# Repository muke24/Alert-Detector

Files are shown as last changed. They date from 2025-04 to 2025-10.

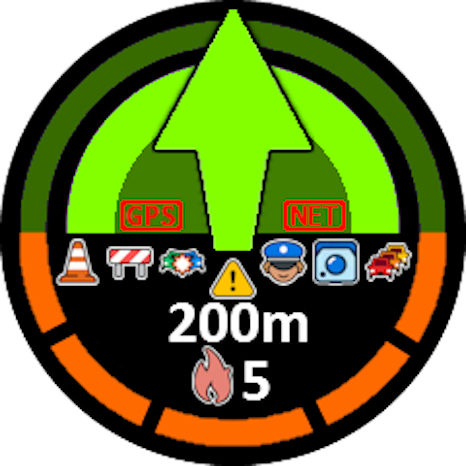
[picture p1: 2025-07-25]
Source/Images/Design/Design466.png

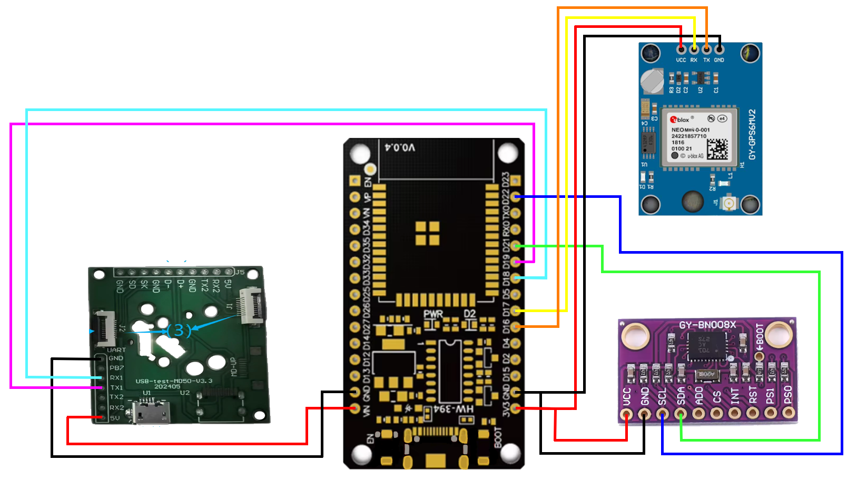
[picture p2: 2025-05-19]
Project Documents/Wiring Diagrams/V1/WiringDiagramV1.png

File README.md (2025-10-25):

Made for fun. I'd love for likeminded individuals to help with this project. I've been working on this idea for 3 years on and off, so make good use of it.

----------------------------------------
Description:

This project was inspired by the original Need for Speed Most Wanted (2005) which includes a device that uses Waze alert data which currently only points towards the closest police car. A really cool project which scrapes Waze API alert data (currently only POLICE alerts) and displays an arrow pointing towards the closest alert. It also shows the heat level, determined by how many police alerts are in the area. Along with that, the icon for the alert which was detected is also displayed, so if there are 3 police cars in the vicinity then 3 police icons will be shown.
The distance of the closest alert is also shown. Alert submission back to Waze does not exist, but if someone figured out how to, that would be cool.

This used to work perfectly, and if you use the Waze URL found within the code and paste it in to your search bar, you'll still see the JSON containing all of the alerts.
I think Waze may have patched this for devices which doesn't send cookie data, like this ESP32, but with some hacking around I think someone could get past this.
This code can be found in "Code/1_75 Inch/AlertFinder/AlertRetriever.cpp". Keep in mind this is a Waze backdoor API URL, use at your own risk. This could be changed at any time which it seems that some sort of security with it has changed and has not been working recently with the ESP32's I have tested recently. It still works within a Unity application as of currently - https://github.com/muke24/Civic_03

Uses DIY knob as inspiration found at https://github.com/scottbez1/smartknob. The youtube video I followed was: https://www.youtube.com/watch?v=ip641WmY4pA.
I used this as I did not want a cheap feel to the device, and makes it more premium and is stronger than a regular rotary encoder like an EC35 rotary encoder.
I also did not want to explicitly use touch, as touch screens and cars don't work well together in my humble opinion, so I wanted to use the touch screen as a sensor to know when the knob is pushed down, which would in theory make a haptic like vibration to replicate a button press. This has not been completed, but that was the idea.

I'd love to add a dashcam functionality and even AI detection of alerts, however the current device runs at about 15 frames per second, so this is not viable with this setup.
A Jetson Nano should do that job well, but that would get expensive. Definitely something I want to make though.

----------------------------------------

Data Source Warning: 
The device currently uses a reverse-engineered, non-public Waze URL. 
This method is fragile and likely violates Waze's Terms of Service. The URL is currently broken for the device (unsure of why, it works perfectly within Unity and it DID used to work on this ESP32, one day it just stopped working, not sure exactly what it is related to but AI told me its something to do with cookies, so there is a head start, maybe I just missed something, and if not I can already think of a few dodgy work arounds eg. get a server to pull the data instead and then get this device to pull from the server), 
so the first challenge for the community is to fix the access method. All code is provided under the MIT license."

----------------------------------------

PCB Warning:
PCB is untested. It is used to connect the ESP32 to the modules and power management. The ESP32 connects to this PCB by feeding 28AUG enameled copper wires through the hollow shaft motor. Do not hot glue the enamelled wires directly to the ESP32, but solder them onto the end of a 8 pin male header and push that into the device, seems to work pretty well.

----------------------------------------

Files for Creation

- Code: "Code/1_75 Inch/AlertFinder.ino"
- Models: "Models/13" (Read the README file in Models folder)
- PCB Files: PCB/1_75/kiCadWiringDiagram2025aug29/kiCadWiringDiagram

Parts: 
- ESP32: Waveshare 1.75Inch AMOLED ESP32-S3 (with GPS and Speaker) - https://www.waveshare.com/esp32-s3-touch-amoled-1.75.htm
- LED: (48leds used) 160 LEDs/m WS2812B 2.7mm width - https://www.aliexpress.com/item/1005006697141669.html?spm=a2g0o.order_list.order_list_main.172.643b18023ERucf
- Motor: 2804 iFlight Ipower - https://www.aliexpress.com/item/1005008389835260.html?spm=a2g0o.order_list.order_list_main.67.7c741802dJIMvc
(will test cheaper model eventually, I received 3 different types, there was a cheaper one that would have worked with some modeling work to add an encoder {https://www.aliexpress.com/item/4001123251754.html?spm=a2g0o.order_list.order_list_main.77.7c741802dJIMvc} but I received the iFlight first)
- PCB (To be sent to manufacturer JLCPCB)
- 28AUG Enamelled Wire
- 8 pin 2.54mm male header
- 10 Pin JST XH male header

On PCB:
- Magnetometer: MMC5883 (on PCB)
- Motor controller: TMC6300-LA (Might be changed on PCB if no stock is available)

M2 screws used.

----------------------------------------

TODO:

- Remove wire tray from "15" model and rename that to "16". (It was added to test things before I got a PCB manufactured, but even the tray was never used, so will need to fix that up)
- Code haptics and knob control for the motor
- Code LED's
- Code the magnetometer (merge the MMC5883 with the built-in 6 axis IMU on the Waveshare device to create a 9-axis IMU so that compass will work accurately)
- Code other Waze alerts and subtypes
- Code user settings so that brightness / selected alerts / ect can be modified
- Model universal mirror mounts so that the device can be held in place

Untested:
I have not yet manufactured a PCB.
I have not tested or coded the motor functionality. The motor will be used for haptics, and knob rotation feedback and selecting options such as changing alerts, brightness ect (not coded yet but you get the idea).
LED's have not yet been tested.
Pretty much anything connecting to the PCB hasn't been tested yet. I do however have coded all of these functions (except motor function) on the old version of this device (in the "Old" folder).

I do not want precise touch functionality, touch only exists to detect button presses. A mini touch screen makes no sense on a device made for use in a car to specifically reduce the need to even look at the Waze app for alert info.

I did make a different version with different parts. It was ugly and no model was made for it, but functionally it worked entirely (encoder worked, LED's worked and would flash at a speed dependant on how far the closest alert was, GUI was functional but showed no colour and was ugly, the arrow pointed at the closest police alert, speaker made OG NFSMW radar sounds which also played repeatedly dependant on how far the closest alert was). This can be found somewhere in the "Old" folder. I've provided Google Drive links with videos of the old version working with real alerts.

----------------------------------------

Additional Remarks:

If I were to pick and choose any future ideas, I would do this -

Models
Multiple models with differing price ranges:
- Cheapest: 1.46i Waveshare AMOLED with regular rotary encoder. Similar design to how it is now but cheaper and simpler. (Around $120 AUD)
- Mid Range: 1.75i Waveshare AMOLED (this design) but with added dashcam functionality. (Around $275 AUD)
- Flagship: 1.75i AMOLED using Nvidia Jetson Nano with dashcam and AI alert auto detection (Around a steap $850 AUD). (I know this is pretty ambitious, wanna team up Waze?)

Software
- A phone app to change settings and view dashcam videos if it were to be added. 
- AI Auto detection of alerts via camera.
- Alert Reporting

Hardware
- (Flagship) Dual PTZ Camera's for better long distance accuracy. LIDAR won't work through glass.
- (Flagship) Custom PCB built within the enclosure instead of the knob.

----------------------------------------

Pictures taken throughout development:

https://github.com/user-attachments/assets/8ef88b90-4c08-46e0-89e6-efae050536bf









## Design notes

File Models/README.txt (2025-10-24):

The "13" model is the one seen in the pictures on the GitHub.

The bottom tray was added in 14 & 15 as I was assuming I was going to wire everything together and put the wires inside the bottom tray, but it's cheaper and easier if a PCB is made, so I hired a freelancer to do it. They weren't able to complete within budget as there were some issues that were needed to be fixed.

Also, "14" and "15" have the GPS holder, which will need to be added to "13". Either modify "13" to have the GPS holder, or remove the tray on "15".

Specifically,
JLCPCB didn't have stock of the motor controller, and PCBWay replied saying there was an issue:

"In your gerber files, some pads clearance in copper layer is smaller than 0.22mm,
therefore, solder mask bridge is not available. If you need black solder mask in these areas
as the attached pic1 showed, pls enlarge space to 0.22mm or there will be no solder mask
between those pads, which may cause short circuit. Pls check and advise".

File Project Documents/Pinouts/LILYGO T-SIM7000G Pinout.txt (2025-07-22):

LILYGO T-SIM7000G V1.1 Pinout

Left side:
       |        |       | 3V3
       |        |       | GND
Pin 32 | GPIO32 | ADC04 | TOUCH9
Pin 33 | GPIO33 | ADC05 | TOUCH8
Pin 34 | GPIO34 | ADC06 | TOUCH7
Pin 35 | GPIO35 | ADC07 | TOUCH6
Pin 25 | GPIO25 | DAC1  | 
Pin 26 | GPIO26 | DAC2  | 
Pin 27 | GPIO27 | ADC17 | TOUCH0
Pin 14 | GPIO14 | ADC12 | TOUCH2
Pin 13 | GPIO13 | ADC14 | TOUCH4
Pin 12 | GPIO12 | ADC15 | TOUCH5
       |        |       | VBAT

Right side (the side with USB-C port):
Pin 1  | GPIO01 |       | Serial TX
Pin 3  | GPIO03 |       | Serial RX
Pin 22 | GPIO22 |       | Wire_SCL
Pin 21 | GPIO21 |       | Wire_SDA
Pin 23 | GPIO23 |       | VSPI_MOSI
Pin 19 | GPIO19 |       | VSPI_MISO
Pin 18 | GPIO18 |       | VSPI_SCK
Pin 5  | GPIO5  |       | VSPI_SS
Pin 39 | GPIO39 | ADC03 | S_VN
Pin 36 | GPIO36 | ADC0  | S_VP
Pin 0  | GPIO0  | ADC1T | TOUCH1
       |        |       | RST
       |        |       | VIN

Reserved pins:
Function		GPIO Pin	Description
SD Card MISO		2	Data input for SD card via SPI
SD Card MOSI		15	Data output for SD card via SPI
SD Card SCK		14	Clock signal for SD card via SPI
SD Card CS		13	Chip select for SD card via SPI
SIM7000G RX		26	Receive line for UART communication
SIM7000G TX		27	Transmit line for UART communication
SIM7000G PWR		4	Power control pin for the module
SIM7000G RESET		5	Reset pin for the module
SIM7000G DTR		25	Data Terminal Ready for serial control
On-board LED (Blue)	12	Indicator LED on the board
Battery ADC		35	Analog input for battery voltage sensing
Solar ADC		36	Analog input for solar panel voltage

Modules attached to LILYGO T-SIM7000G V1.1 (ignoring power):
- LED Strip: "WS2812B Data" to "GPIO14"
- Adafruit Stemma Speaker: "Signal" to "GPIO25"
- Adafruit LSM6DSOX + LIS3MDL: "SCL" to "GPIO22", "SDA" to "GPIO21"
- Waveshare 1.28in Display: "DIN" to "GPIO23", "CLK" to "GPIO18", "CS" to "GPIO19", "DC" to "GPIO32", "RST" to "GPIO33", "BL" to "GPIO12"

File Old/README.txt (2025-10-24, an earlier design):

There is some old versions of this project using different parts.

I got this working on a LILYGO T-SIM7000G and a Viewe ESP32C3 Round knob display (no touch). Everything worked with REAL data, and videos of it working can be found with this Google drive link:
https://drive.google.com/drive/folders/1Ry67S7yOqGGwLOj_nvCzGusXf9WcztDI?usp=drive_link

The idea was to have it working with LTE alongside WI-FI, but I learnt that every SIM carrier would need to be coded specifically for it to work, so I gave up on that idea after too much time not even getting my own carrier to work.

The first ever version was actually inside of a Unity Project which I was just messing around with to add it to my Android headunit of my Civic, and this project started the second I saw it working in Unity.

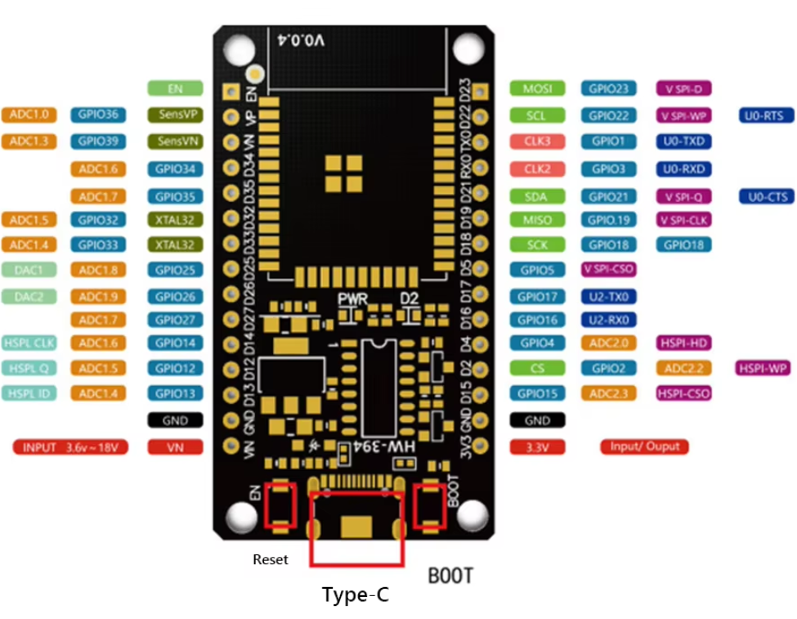
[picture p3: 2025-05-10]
Project Documents/Specsheets/ESP32-WROOM-32D Pinout.png

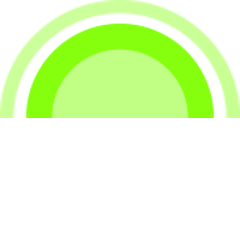
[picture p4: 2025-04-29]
Source/Images/background.png

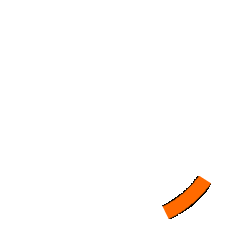
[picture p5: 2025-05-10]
Source/Images/In Use/Resources/Heat/heatBar4_full_img.png

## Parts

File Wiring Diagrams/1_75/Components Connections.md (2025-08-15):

**Components:**

**ESP32:** The microcontroller that controls everything.

Pins: GPIO19, GPIO18, GPIO17, 3v3, GND, VBUS, SCL, SDA, SPKR+, SPKR-, GPS+, GPS-.

**12V to 5V Buck Converter:** To step down the input voltage for the ESP32 and LED strip.

Pins: Input +, Input -, Output +, Output -.

**XL6009E1 Boost Converter:** To step up the 5V to 10V for the motor.

Pins: Input +, Input -, Output +, Output -.

**WS2812B 48 LED Strip:** The addressable LED lights.

Pins: +, -, Data

**iFlight iPower GM2804 Motor:** The brushless gimbal motor with the built-in ESC.

Pins: +, -, PWM

**MMC5603 Magnetometer:** A sensor for magnetic fields.

Pins: (UART) +, -, SDA, SCL

**AS5048A Encoder:** A sensor for rotational position.

Pins: (UART) +, -, PWM

**Schottky Diodes (x2):** For protecting the two power inputs.

Pins: Input, Output

**GPS:** Can be ignored as it's just the antenna with a regular RF wire. Included for clarification.

**Connection List:**

**ESP32 Connector:**

* GPIO19 to Encoder.PWM
* GPIO18 to Motor.PWM
* GPIO17 to LED\_Strip.Data
* 3v3 to 3V3\_Rail
* GND to GND\_Rail
* VBUS to 5V\_Rail
* SCL to MMC5603.SCL
* SDA to MMC5603.SDA
* SPKR+, SPKR-, GPS+, GPS- are Not Connected

**12V to 5V Buck Converter:**

* Input+ to 12V\_Rail
* Input- to GND\_Rail
* Output+ to 5V\_Rail
* Output- to GND\_Rail

**XL6009E1 Boost Converter:**

* Input+ to 5V\_Rail
* Input- to GND\_Rail
* Output+ to Motor.+
* Output- to GND\_Rail

**WS2812B 48 LED Strip:**

* \+ to 5V\_Rail
* \- to GND\_Rail
* Data to ESP32.GPIO17

**iFlight iPower GM2804 Motor:**

* \+ to Boost\_Converter.Output+
* \- to GND\_Rail
* PWM to ESP32.GPIO18

**MMC5603 Magnetometer:**

* \+ to 3V3\_Rail
* \- to GND\_Rail
* SDA to ESP32.SDA
* SCL to ESP32.SCL

**AS5048A Encoder (3-pin PWM version):**

* \+ to 3V3\_Rail
* \- to GND\_Rail
* PWM to ESP32.GPIO19

**Schottky Diode 1:**

* Input to Barrel\_Jack.+
* Output to 12V\_Rail

**Schottky Diode 2:**

* Input to Direct\_Connect.+
* Output to 12V\_Rail

**Barrel Jack Input:**

* \+ to Schottky\_Diode\_1.Input
* \- to GND\_Rail

**Direct Connect Input:**

* \+ to Schottky\_Diode\_2.Input
* \- to GND\_Rail

**Wiring:**

This section describes the physical connections to each module, all module pins have female connectors.

**ESP32 Connector:**

* GPIO19**:** M-M wire to Encoder PWM
* GPIO18: M-M wire to Motor PWM
* GPIO17: M-M wire to LED Strip Data
* 3v3: M-M wire to 3V3\_Rail splitter
* GND: M-M wire to GND\_Rail splitter
* VBUS: M-M wire to 5V\_Rail splitter
* SCL: M-M wire to MMC5603 SCL
* SDA: M-M wire to MMC5603 SDA

**12V to 5V Buck Converter:**

* Input+: M-M wire to 12V\_Rail splitter
* Input-: M-M wire to GND\_Rail splitter
* Output+: M-M wire to 5V\_Rail splitter
* Output-: M-M wire to GND\_Rail splitter

**XL6009E1 Boost Converter:**

* Input+: M-M wire to 5V\_Rail splitter
* Input-: M-M wire to GND\_Rail splitter
* Output+: M-M wire to Motor +
* Output-: M-M wire to GND\_Rail splitter

**WS2812B 48 LED Strip:**

* +: M-M wire to 5V\_Rail splitter
* -: M-M wire to GND\_Rail splitter
* Data: M-M wire to ESP32 GPIO17

**iFlight iPower GM2804 Motor:**

* +: M-M wire to Boost Converter Output+
* -: M-M wire to GND\_Rail splitter
* PWM: M-M wire to ESP32 GPIO18

**MMC5603 Magnetometer:**

* +: M-M wire to 3V3\_Rail splitter
* -: M-M wire to GND\_Rail splitter
* SDA: M-M wire to ESP32 SDA
* SCL: M-M wire to ESP32 SCL

**AS5048A Encoder:**

* +: M-M wire to 3V3\_Rail splitter
* -: M-M wire to GND\_Rail splitter
* PWM: M-M wire to ESP32 GPIO19

**Wires Needed:**

This is an inventory of the jumper wires required to assemble the project.

**Splitter Cables (to create power/ground rails):**

* **(x4) Male to 3x Male Splitter:**

&nbsp;	- One for the 5V\_Rail (connects Buck, Boost, ESP32, LED).

&nbsp;	- Three linked together for the GND\_Rail (connects all 11 ground points).

* **(x2) Male to 2x Male Splitter:**

&nbsp;	- One for the 3V3\_Rail (connects ESP32, Encoder, MMC5603).

&nbsp;	- One for the 12V\_Rail (connects both Diodes, Buck Input).

**Standard Point-to-Point Wires:**

* **(x10) Male to Male Wires:**

&nbsp;	- 2 for the 12V inputs to the diodes.

&nbsp;	- 1 for ESP32.GPIO17 to LED.Data.

&nbsp;	- 1 for ESP32.GPIO18 to Motor.PWM.

&nbsp;	- 1 for ESP32.GPIO19 to Encoder.PWM.

&nbsp;	- 1 for Boost.Output+ to Motor.+.

&nbsp;	- 2 for the SDA/SCL lines between the ESP32 and MMC5603.

&nbsp;	- 2 for connecting the main power sources to the project.

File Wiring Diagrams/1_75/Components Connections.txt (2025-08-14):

Components:

ESP32: The microcontroller that controls everything.
Pins: GPIO19, GPIO18, GPIO17, 3v3, GND, VBUS, SCL, SDA, SPKR+, SPKR-, GPS+, GPS-.

12V to 5V Buck Converter: To step down the input voltage for the ESP32 and LED strip.
Pins: Input +, Input -, Output +, Output -.

XL6009E1 Boost Converter: To step up the 5V to 10V for the motor.
Pins: Input +, Input -, Output +, Output -.

WS2812B 48 LED Strip: The addressable LED lights.
Pins: +, -, Data

iFlight iPower GM2804 Motor: The brushless gimbal motor with the built-in ESC.
Pins: +, -, PWM

MMC5603 Magnetometer: A sensor for magnetic fields.
Pins: (UART) +, -, SDA, SCL

AS5048A Encoder: A sensor for rotational position.
Pins: (UART) +, -, SDA, SCL

Schottky Diodes (x2): For protecting your two power inputs.
Pins: Input, Output

GPS: Can be ignored as it's just the antenna with a regular RF wire. Included for clarification.

Connection List:
TODO: Complete Connections

ESP32 Connector: "GPIO19" to "PWM" of "Encoder", "GPIO18" to "Data" of "LED strip", "GPIO17" to "PWM" of "Motor", "3v3" to "+" of "MMC5603 and "+" of "Encoder", "GND" to "-" of "Encoder and "-" of "LED strip" and "-" of "MMC5603" and "Input-" of "Boost Converter" and "Output-" of "Buck Converter", "VBUS" to "Input+" of "Boost Converter" and "Output+" of "Buck Converter", "SCL" to "SCL" of "MMC5603", "SDA" to "SDA" of "MMC5603", "SPKR+" to "+" of "Speaker", "SPKR-" to "-" of "Speaker", "GPS+" to "+" of "GPS", "GPS-" to "-" of "GPS".

12V to 5V Buck Converter: "Input+" to "Output" of "Schottky Diode 1" and "Output" of "Schottky Diode 2", "Input-" to "-" of "Barrel Jack" and "-" of "Direct Connect", "Output+" to "Input+" of "Boost Converter" and "+" of "LED strip", "Output-" to "Input-" of "Boost Converter".

XL6009E1 Boost Converter: "Input+" to "+" of "LED strip" and "Output+" of "Buck Converter" and "VBUS" of "ESP32", "Input-" to "?", "Output +" to "?", "Output -" to "?".

WS2812B 48 LED Strip: "+" to "?", "-" to "?", "Data" to "?"

iFlight iPower GM2804 Motor: "+" to "?", "-" to "?", "Data" to "?"

MMC5603 Magnetometer: "+" to "?", "-" to "?", "SDA" to "?", "SCL" to "?"

AS5048A Encoder: "+" to "?", "-" to "?", "SDA" to "?", "SCL" to "?"

Schottky Diode 1:

Schottky Diode 2:

Barrel Jack Input:

Direct Connect Input:

Wiring:
TODO: Complete the connector types for each module (ignore GPS).
I will solder the following connectors to each pin of each module.
- Male jumper wire
- Female jumper wire

(Use the ESP32 as an example)
ESP32 Connector: Solder male connectors to all wires coming from ESP32.
- VBUS:

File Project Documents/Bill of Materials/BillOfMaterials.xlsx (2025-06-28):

Part Name | Functionality | URL | Price (AUD with shipping + tax) | Github / Code Example | Datasheet
LILYGO T-SIM7000G | Compute/LTE/GPS | https://vi.aliexpress.com/item/4000542688096.html | $57.56 | https://github.com/Xinyuan-LilyGO/LilyGO-T-SIM7000G | https://github.com/Xinyuan-LilyGO/LilyGO-T-SIM7000G/tree/master/docs/SIM7000
BNO086 | Compass | https://vi.aliexpress.com/item/1005006887288697.html | $39.59 | https://github.com/adafruit/Adafruit_BNO08x | https://docs.cirkitdesigner.com/component/6cb86875-6739-408e-baaa-78cacc5bf622/imu
Viewe 1.28i Screen w ESP32C3 | Render/Control | https://vi.aliexpress.com/item/1005007574801988.html | $30.13 | https://github.com/VIEWESMART/UEDX24240013-MD50ESP32_1.3inch-Knob | https://github.com/VIEWESMART/UEDX24240013-MD50ESP32_1.3inch-Knob/blob/main/information/UEDX24240013-MD50E%20V3.3%20SPEC.pdf
144L/m Side Emitting RGB Strip | Visualise Alert Distance | https://www.superlightingled.com/sk6812-rgb-dc5v-8mm-144ledsm-4020-side-emitting-individually-addressable-led-strip-lights-p-4503.html | $23.60 | https://github.com/Electry/Arduino_SK6812 | https://www.superlightingled.com/PDF/SK6812%20RGB+LED+datasheet+.pdf
Adafruit STEMMA Speaker | Audiate Alert Distance | https://core-electronics.com.au/adafruit-stemma-speaker-plug-and-play-audio-amplifier.html | $12.30 | https://learn.adafruit.com/stemma-audio-amp/arduino | https://cdn-learn.adafruit.com/downloads/pdf/adafruit-stemma-speaker.pdf
LED Diffuser | Distribute Lighting | https://vi.aliexpress.com/item/1005004451720515.html | $8.12 | N/A | N/A
3D Printed Case | Combine Components | N/A | $5 | N/A | N/A
 |  |  | Total: $176.30

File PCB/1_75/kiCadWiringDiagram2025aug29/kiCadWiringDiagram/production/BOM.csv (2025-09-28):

Designator | Footprint | Quantity | Value | LCSC Part #
C1, C10, C11, C12, C7, C8, C9 | 0805 | 7 | CL21B104KBCNNNC
C13, C2, C3, C4, C5 | CP_Elec_6.3x5.4 | 5 | FVH016ADA101M0654
C6 | 0805 | 1 | CC0805JRNPO9BN271
D1, D2, D3, D4 | D_SMA | 4 | C437199
F1, F2 | 1206 | 2 | SMD1206P025TF
J1 | JST_XH_S10B-XH-A-1_1x10_P2.50mm_Horizontal | 1 | S10B-XH-A-1(LF)(SN)
J2, J3, J4 | JST_XH_S3B-XH-A-1_1x03_P2.50mm_Horizontal | 3 | S3B-XH-A-1(LF)(SN)
J5, J6 | JST_XH_S2B-XH-A-1_1x02_P2.50mm_Horizontal | 2 | S2B-XH-A-1(LF)(SN)
J7 | JST_GH_BM02B-GHS-TBT_1x02-1MP_P1.25mm_Vertical | 1 | BM02B-GHS-TBT(LF)(SN)
L1, L2 | L_7.3x7.3_H4.5 | 2 | SMDRI74-330MT
R1 | 0805 | 1 | 0805W8J0102T5E
R2 | 0805 | 1 | 0805W8F6801T5E
R3, R4 | 0805 | 2 | 0805W8F2701T5E
R5 | 0805 | 1 | 0805W8F1800T5E
R6 | 0805 | 1 | 0805W8F330LT5E
U1 | TO-263-5_TabPin3 | 1 | LM2596S-5.0
U2 | SOIC-8_3.9x4.9mm_P1.27mm | 1 | MC34063ADR2G
U3 | XDCR_MMC5603NJ | 1 | MMC5603NJ
U4 | QFN40P300X300X90-21N | 1 | TMC6300-LA
U5 | QFN-28-1EP_6x6mm_P0.65mm_EP4.25x4.25mm | 1 | MCP23017T-E/ML

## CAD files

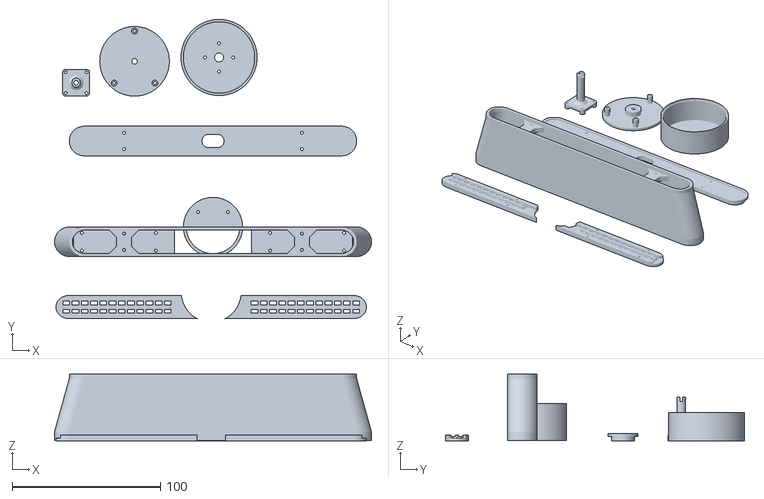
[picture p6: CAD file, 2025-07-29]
Models/10/Print/PoliceRadar10.stl
214.0 x 202.0 x 45.1

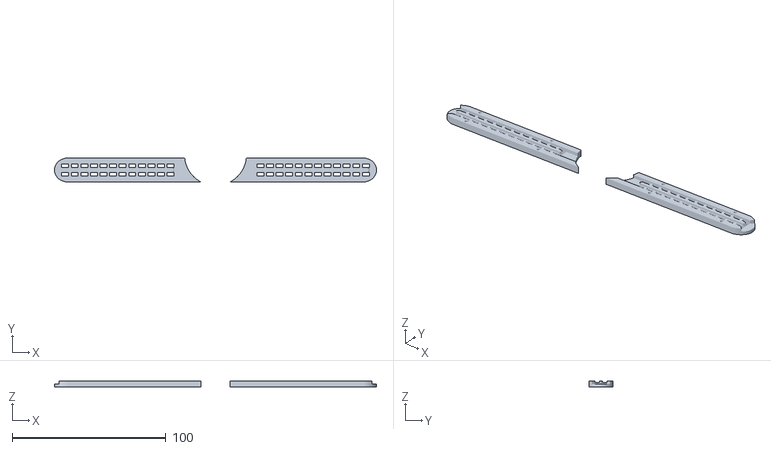
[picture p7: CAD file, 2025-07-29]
Models/10/Print/Separate/LedRack10.stl
209.6 x 15.6 x 4.00

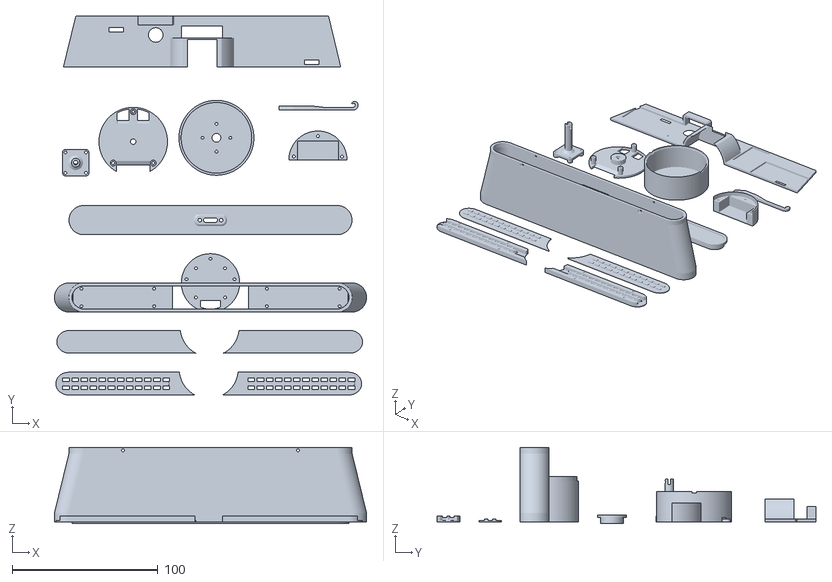
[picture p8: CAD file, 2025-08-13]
Models/15/Print/PoliceRadar14.stl
214.0 x 259.8 x 52.1

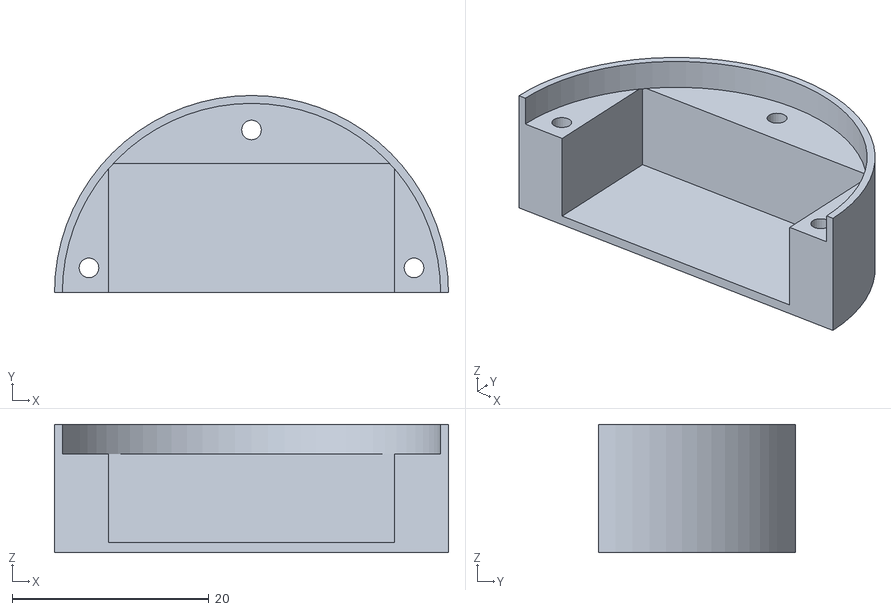
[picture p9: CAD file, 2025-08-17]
Models/15/Print/Separate/GpsHolder.stl
40.0 x 20.0 x 13.0

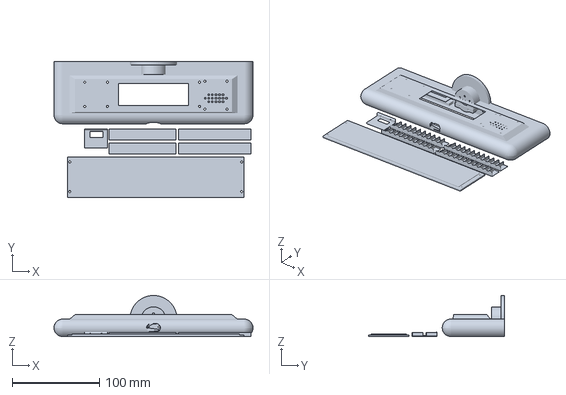
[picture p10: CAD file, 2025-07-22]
Models/3D Prints/PoliceRadarPrototype_10.3mf
228.0 x 155.5 x 47.0 mm

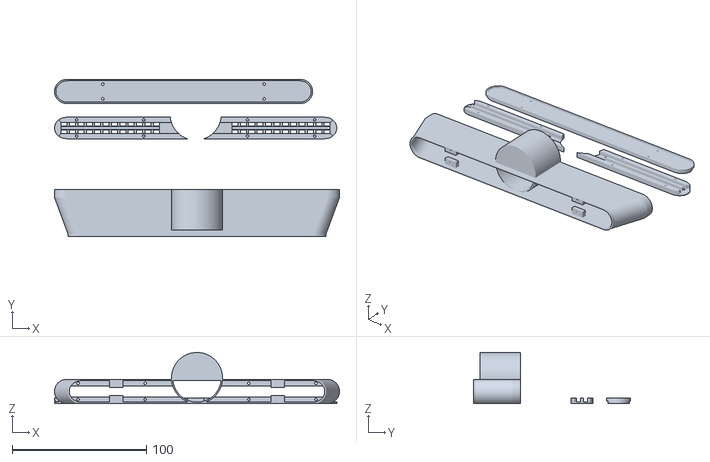
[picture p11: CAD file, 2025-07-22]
Models/New Small/Enclosure/01/Print/PoliceRadar04_Flipped.stl
212.0 x 117.0 x 38.0

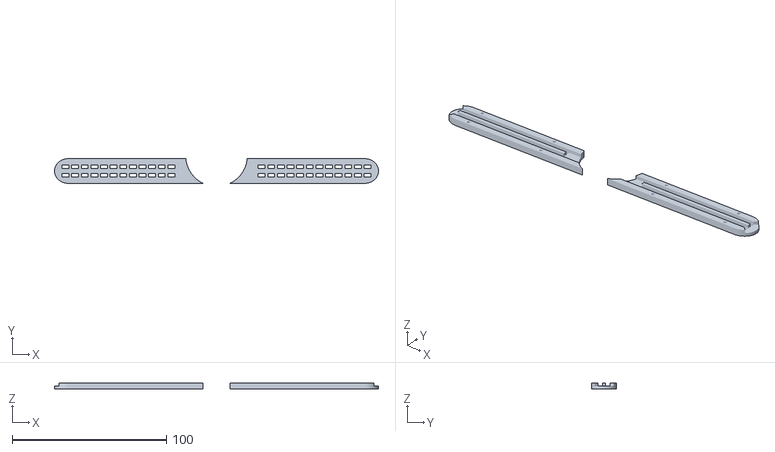
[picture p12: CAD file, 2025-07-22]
Models/New Small/Enclosure/01/Print/Separate/05/PoliceRadar05_LedRack.stl
210.0 x 16.0 x 4.00

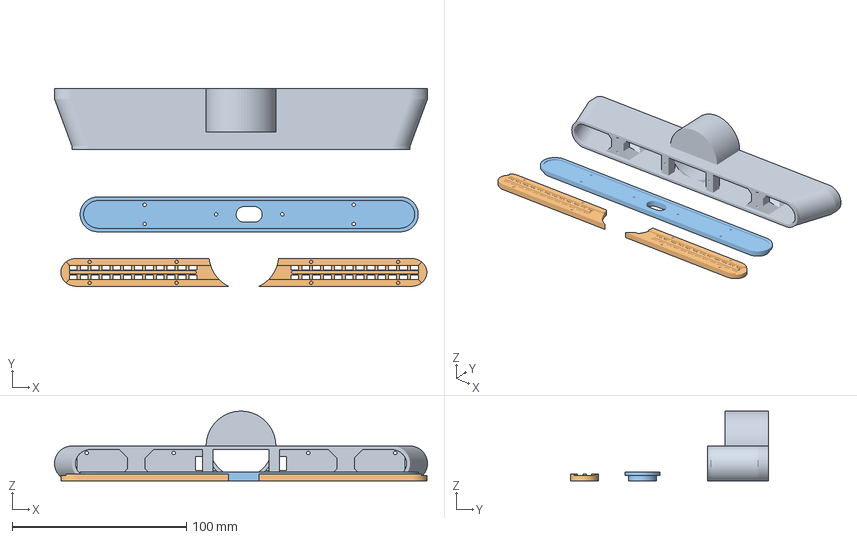
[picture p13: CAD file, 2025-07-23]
Models/New Small/Enclosure/01/Print/Separate/06/PoliceRadar06_Enclosure.3mf
214.0 x 113.4 x 40.0 mm
PoliceRadar06_Enclosure.stl
PoliceRadar06_LedRack.stl
PoliceRadar06_Lid.stl

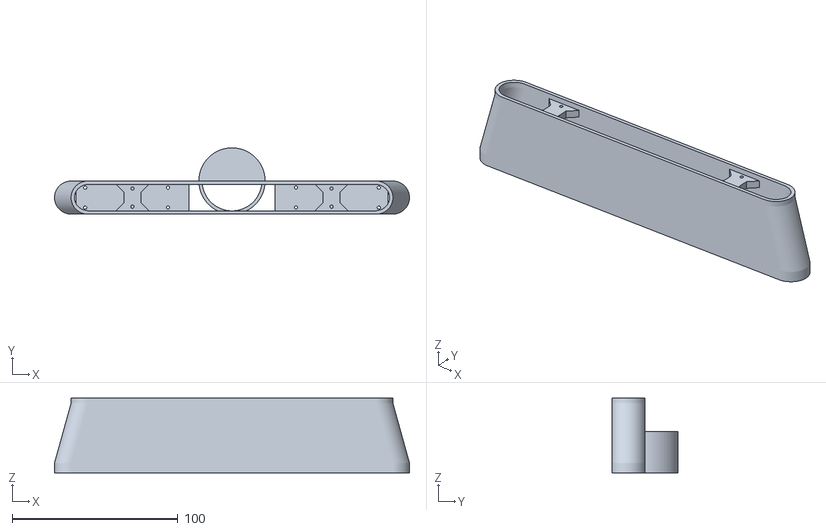
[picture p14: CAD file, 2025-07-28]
Models/New Small/Enclosure/01/Print/Separate/09/PoliceRadar09Enclosure_Flipped.stl
214.0 x 40.0 x 45.0

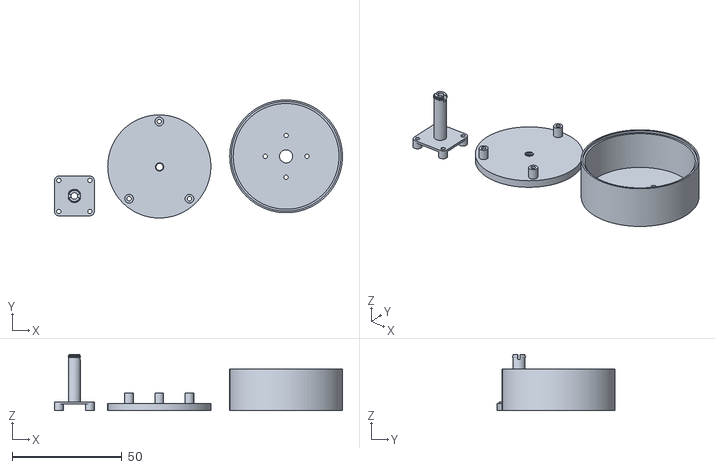
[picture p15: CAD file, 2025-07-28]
Models/New Small/Enclosure/01/Print/Separate/Knob/02/Knobs.stl
131.2 x 53.8 x 25.5

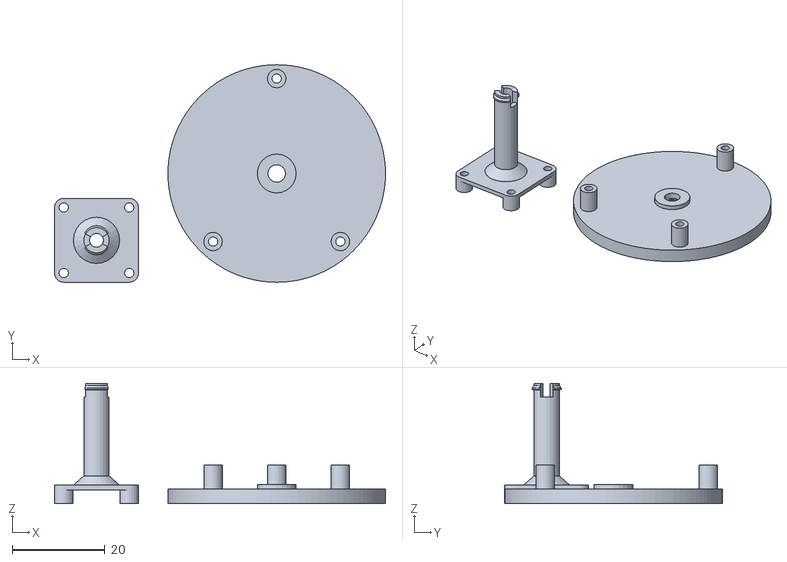
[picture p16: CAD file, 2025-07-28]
Models/New Small/Enclosure/01/Print/Separate/Knob/03/Adapter06Holder.stl
71.5 x 47.0 x 26.0

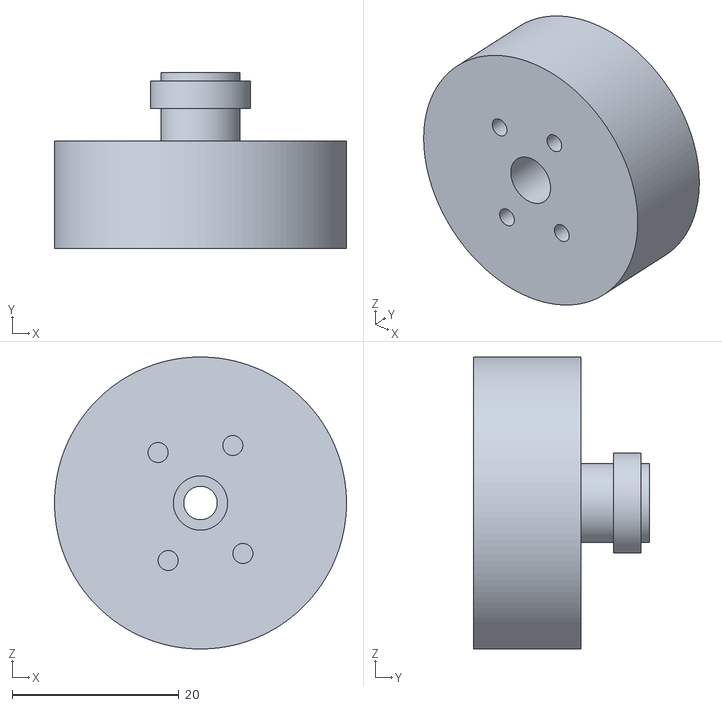
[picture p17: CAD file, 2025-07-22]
Models/New Small/iPower GM2804 Motor.stl
35.0 x 21.1 x 35.0

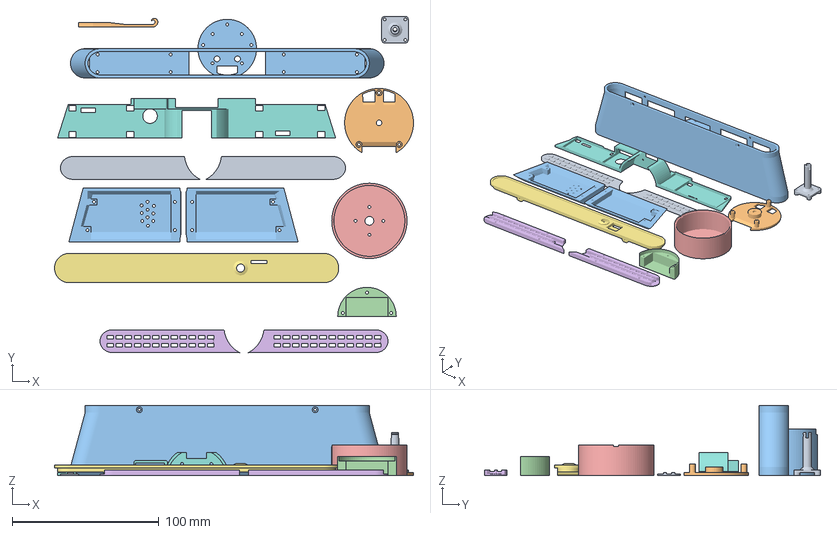
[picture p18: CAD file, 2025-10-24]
Models/PoliceRadar01_Flat.3mf
245.0 x 229.5 x 48.0 mm
Adapter.stl
AdapterHolder.stl
Enclosure.stl
GpsHolder.stl
Knob.stl
LedRack.stl
Lid.stl
ModuleHolder.stl
TransparentFrontPanel.stl
WireHook.stl
WireTrays.stl

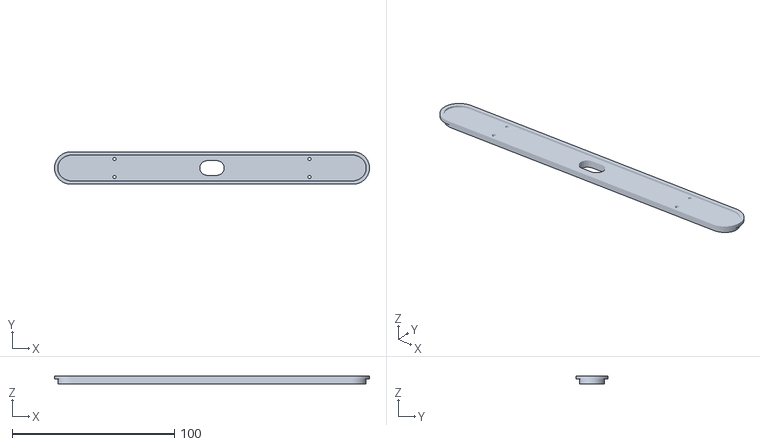
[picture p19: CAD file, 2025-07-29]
Models/10/Print/Separate/Lid10.stl
194.0 x 20.0 x 5.00

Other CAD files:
Models/New Small/Enclosure/01/Print/Separate/07/PoliceRadar07_LedRack.stl
Models/New Small/Enclosure/01/Print/Separate/Knob/Knobs03.stl
Models/New Small/Enclosure/Prints/PoliceRadar01_Flat.3mf
Models/15/Print/Separate/ModuleHolder.stl
Models/10/PoliceRadar10.skp
Models/10/Print/Separate/Adapter10.stl
Models/10/Print/Separate/Enclosure10.stl
Models/10/Print/Separate/Holder10.stl
Models/10/Print/Separate/Knob10.stl
Models/11/PoliceRadar11.skp
Models/12/PoliceRadar12.skp
Models/12/Print/Separate/Adapter.stl
Models/12/Print/Separate/Enclosure.stl
Models/12/Print/Separate/Holder.stl
Models/12/Print/Separate/Knob.stl
Models/12/Print/Separate/LedRack.stl
Models/12/Print/Separate/Lid.stl
Models/13/PoliceRadar13.skp
Models/13/Print/Separate/Adapter.stl
Models/13/Print/Separate/Enclosure.stl
Models/13/Print/Separate/Holder.stl
Models/13/Print/Separate/Knob.stl
Models/13/Print/Separate/LedRack.stl
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

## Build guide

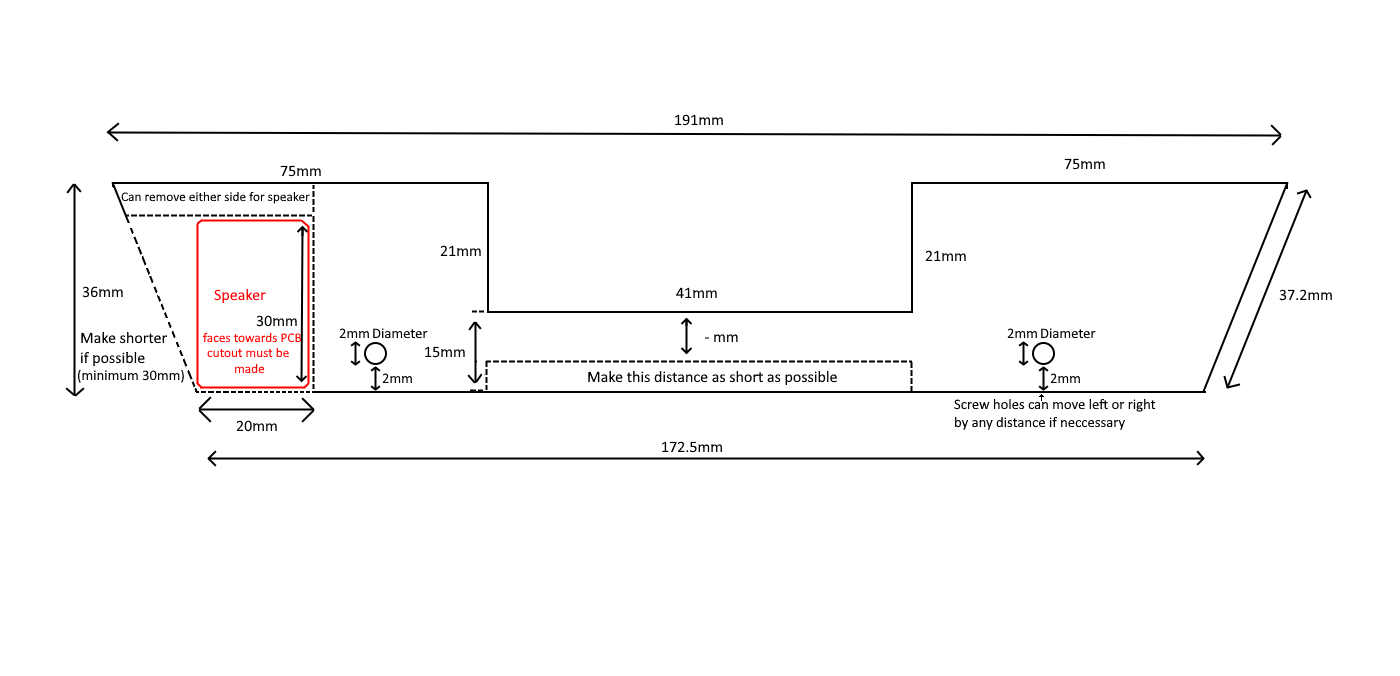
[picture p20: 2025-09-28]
Wiring Diagrams/1_75/Hire/pcbShape2.png

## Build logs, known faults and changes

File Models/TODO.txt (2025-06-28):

- Make horizontal split through center to allow device to separate top from bottom and add screw holes in top
- Make the front of the device screw on. This will separate the LED rack from the device itself.

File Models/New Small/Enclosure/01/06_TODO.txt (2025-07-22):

- Increase the height of the enclosure by 2mm

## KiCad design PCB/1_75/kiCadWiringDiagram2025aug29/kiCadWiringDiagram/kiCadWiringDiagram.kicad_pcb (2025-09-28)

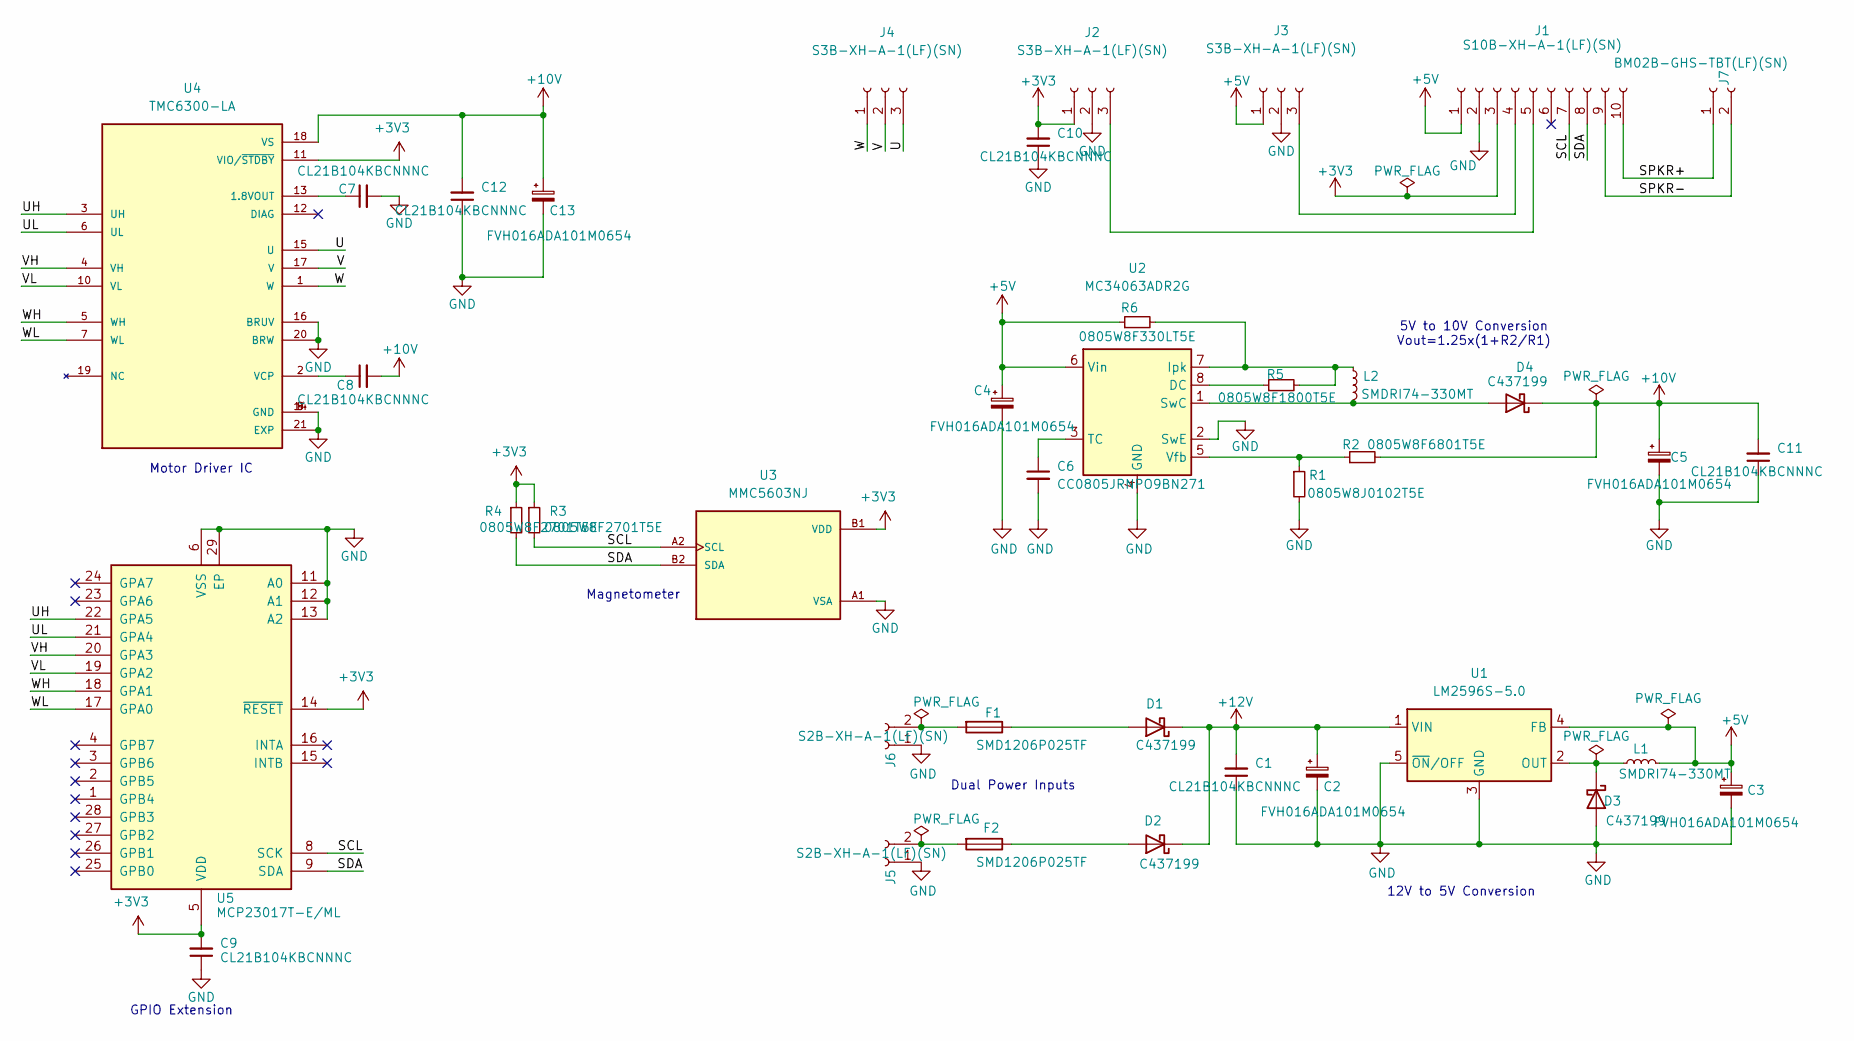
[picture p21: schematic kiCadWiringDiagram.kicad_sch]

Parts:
C1, C7, C8, C9, C10, C11, C12: CL21B104KBCNNNC; C_0805_2012Metric
C2, C3, C4, C5, C13: FVH016ADA101M0654; CP_Elec_6.3x5.4
C6: CC0805JRNPO9BN271; C_0805_2012Metric
D1, D2, D3, D4: C437199; D_SMA
F1, F2: SMD1206P025TF; Fuse_1206_3216Metric
J1: S10B-XH-A-1(LF)(SN); JST_XH_S10B-XH-A-1_1x10_P2.50mm_Horizontal
J2, J3, J4: S3B-XH-A-1(LF)(SN); JST_XH_S3B-XH-A-1_1x03_P2.50mm_Horizontal
J5, J6: S2B-XH-A-1(LF)(SN); JST_XH_S2B-XH-A-1_1x02_P2.50mm_Horizontal
J7: BM02B-GHS-TBT(LF)(SN); JST_GH_BM02B-GHS-TBT_1x02-1MP_P1.25mm_Vertical
L1, L2: SMDRI74-330MT; L_7.3x7.3_H4.5
R1: 0805W8J0102T5E; R_0805_2012Metric
R2: 0805W8F6801T5E; R_0805_2012Metric
R3, R4: 0805W8F2701T5E; R_0805_2012Metric
R5: 0805W8F1800T5E; R_0805_2012Metric
R6: 0805W8F330LT5E; R_0805_2012Metric
U1: LM2596S-5.0; TO-263-5_TabPin3
U2: MC34063ADR2G; SOIC-8_3.9x4.9mm_P1.27mm
U3: MMC5603NJ; XDCR_MMC5603NJ; PARTREV B
U4: TMC6300-LA; QFN40P300X300X90-21N; PARTREV 1.08
U5: MCP23017T-E/ML; QFN-28-1EP_6x6mm_P0.65mm_EP4.25x4.25mm

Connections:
+3V3: C9.2, C10.2, J1.3, J2.1, R3.1, R4.1, U3.B1 (VDD), U4.11 (VIO/~STDBY), U5.5 (VDD), U5.14 (~RESET)
+5V: C3.1, C4.1, J1.1, J3.1, L1.1, R6.1, U1.4 (FB), U2.6 (Vin)
+10V: C5.1, C8.2, C11.2, C12.2, C13.1, D4.1 (K), R2.2, U4.18 (VS)
+12V: C1.2, C2.1, D1.1 (K), D2.1 (K), U1.1 (VIN)
/SCL: J1.7, R3.2, U3.A2 (SCL), U5.8 (SCK)
/SDA: J1.8, R4.2, U3.B2 (SDA), U5.9 (SDA)
/SPKR+: J1.10, J7.1
/SPKR-: J1.9, J7.2
/U: J4.3, U4.15 (U)
/UH: U4.3 (UH), U5.22 (GPA5)
/UL: U4.6 (UL), U5.21 (GPA4)
/V: J4.2, U4.17 (V)
/VH: U4.4 (VH), U5.20 (GPA3)
/VL: U4.10 (VL), U5.19 (GPA2)
/W: J4.1, U4.1 (W)
/WH: U4.5 (WH), U5.18 (GPA1)
/WL: U4.7 (WL), U5.17 (GPA0)
GND: C1.1, C2.2, C3.2, C4.2, C5.2, C6.2, C7.2, C9.1, C10.1, C11.1, C12.1, C13.2, D3.2 (A), J1.2, J2.2, J3.2, J5.1, J6.1, R1.2, U1.3 (GND), U1.5 (~ON/OFF), U2.2 (SwE), U2.4 (GND), U3.A1 (VSA), U4.8 (GND), U4.9 (GND), U4.14 (GND), U4.16 (BRUV), U4.20 (BRW), U4.21 (EXP), U5.6 (VSS), U5.11 (A0), U5.12 (A1), U5.13 (A2), U5.29 (EP)
unnamed: D1.2 (A), F1.1
unnamed: D2.2 (A), F2.1
unnamed: D3.1 (K), L1.2, U1.2 (OUT)
unnamed: D4.2 (A), L2.2, U2.1 (SwC)
unnamed: J1.4, J3.3
unnamed: J1.5, J2.3
unnamed: F2.2, J5.2
unnamed: F1.2, J6.2
unnamed: R5.1, U2.8 (DC)
unnamed: L2.1, R5.2, R6.2, U2.7 (Ipk)
unnamed: C6.1, U2.3 (TC)
unnamed: R1.1, R2.1, U2.5 (Vfb)
unnamed: C7.1, U4.13 (1.8VOUT)
unnamed: C8.1, U4.2 (VCP)

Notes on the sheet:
12V to 5V Conversion
GPIO Extension
Motor Driver IC
5V to 10V Conversion Vout=1.25x(1+R2/R1)
Dual Power Inputs
Magnetometer

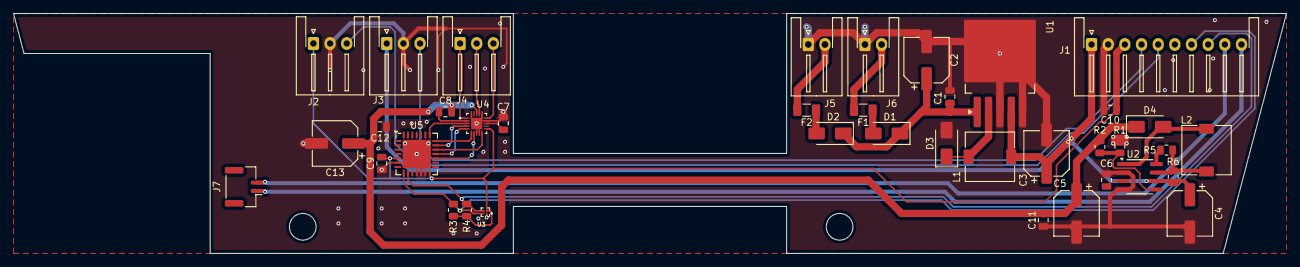
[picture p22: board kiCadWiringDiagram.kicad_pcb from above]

Board: 2 copper layers, 191.0 x 36.0 mm, 39 parts (0 on the bottom side), 32 nets.

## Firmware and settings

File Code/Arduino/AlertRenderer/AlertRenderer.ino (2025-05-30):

// AlertRenderer.ino

// Notes:
// - Dual canvas is intended. Single canvas rotation is not supported by LVGL.

#include <Arduino_GFX_Library.h>
#include <lvgl.h>
#include "freertos/FreeRTOS.h"
#include "freertos/task.h"
#include <Encoder.h>
#include <Bounce2.h>
#include <HardwareSerial.h>

// Pinout for this Viewe 1.28inch ESP32C3 push knob display module.
#define ADC_PIN 3 // GPIO03
#define RX_PIN 20  // GPIO20 RX
#define TX_PIN 21  // GPIO21 TX
#define UART_RECIEVE 0 // UART 0, 1 or 2 // USE UART 0 WITH A 10 PIN FPC EXTENSION BOARD. PIN 1: VCC, PIN 2: GND, PIN 6: RX, PIN 7: TX

#define GFX_BL 8

Arduino_DataBus *bus = new Arduino_ESP32SPI(4 /* DC */, 10 /* CS */, 1 /* SCK */, 0 /* MOSI */, GFX_NOT_DEFINED /* MISO */);
Arduino_GFX *gfx = new Arduino_GC9A01(bus, GFX_NOT_DEFINED /* RST */, 3 /* rotation */, true /* IPS */);

#define ROTARY_ENCODER_A_PIN 7
#define ROTARY_ENCODER_B_PIN 6
#define ROTARY_ENCODER_BUTTON_PIN 9

Encoder myEnc(ROTARY_ENCODER_A_PIN, ROTARY_ENCODER_B_PIN);
Bounce2::Button button = Bounce2::Button();

// UART for communication with LILYGO
HardwareSerial SerialUART(UART_RECIEVE);
float currentAngle = 999.0; // Global angle from LILYGO, initialized to sentinel value

/* Screen resolution */
static uint32_t screenWidth = 240;
static uint32_t screenHeight = 240;
lv_disp_draw_buf_t draw_buf;
lv_color_t *disp_draw_buf1;
lv_color_t *disp_draw_buf2;
lv_disp_drv_t disp_drv;
lv_group_t *group;

/* Last encoder value for tracking changes */
static int32_t last_encoder_value = 0;

// Direction Text
static lv_obj_t *directionTxt;

// Screen background
lv_obj_t *scr; 
// Screen size in pixels (1:1 aspect ratio because screen is round)
const int dimention = 240;

// Compass
lv_obj_t *arc1;
lv_obj_t *arc2;
lv_obj_t *arc3;
const int arc_start = 0; // Applied to all arcs
const int arc_end = 180;  // Applied to all arcs
const int arc1_width = 15;
const int arc1_size = dimention - 25;
const int arc2_width = 35;
const int arc2_size = dimention - 80;
const int arc3_width = 65;
const int arc3_size = dimention - 130;
const int compass_max_angle = 90;

// Compass Arrow
lv_obj_t *source_canvas; // Source canvas for the arrow
lv_obj_t *canvas;        // Destination canvas for rotated arrow
const int arrow_width = 120; // Adjusted to match actual canvas width
const int arrow_height = 120; // Adjusted to match actual canvas height
const int arrow_point_count = 7;

// Color palette
lv_color_t palette_black = LV_COLOR_MAKE(0, 0, 0);
lv_color_t palette_dark_green = LV_COLOR_MAKE(100, 193, 0);
lv_color_t palette_green = LV_COLOR_MAKE(128, 255, 0);

/* Display flushing */
void my_disp_flush(lv_disp_drv_t *disp, const lv_area_t *area, lv_color_t *color_p) {
  uint32_t w = (area->x2 - area->x1 + 1);
  uint32_t h = (area->y2 - area->y1 + 1);
#if (LV_COLOR_16_SWAP != 0)
  gfx->draw16bitBeRGBBitmap(area->x1, area->y1, (uint16_t *)&color_p->full, w, h);
#else
  gfx->draw16bitRGBBitmap(area->x1, area->y1, (uint16_t *)&color_p->full, w, h);
#endif
  lv_disp_flush_ready(disp);
}

/* Encoder read callback */
static void my_encoder_read(lv_indev_drv_t *indev_drv, lv_indev_data_t *data) {
  int32_t current_encoder_value = myEnc.read() / 2;
  data->enc_diff = current_encoder_value - last_encoder_value;
  last_encoder_value = current_encoder_value;
  button.update();
  data->state = button.isPressed() ? LV_INDEV_STATE_PRESSED : LV_INDEV_STATE_RELEASED;
}

/* Update compass arrow angle  */
void update_arrow(lv_timer_t *timer) {
    static float displayedAngle = 0.0; // Current angle displayed by the arrow

    if (currentAngle >= -180.0 && currentAngle <= 180.0) { // Valid angle range
        float targetAngle = currentAngle;
        // Normalize target angle to [-180, 180]
        while (targetAngle < -180.0) targetAngle += 360.0;
        while (targetAngle > 180.0) targetAngle -= 360.0;

        // Smoothly interpolate displayedAngle towards targetAngle
        float delta = targetAngle - displayedAngle;
        if (delta > 180.0) delta -= 360.0; // Handle wrapping
        if (delta < -180.0) delta += 360.0;
        displayedAngle += delta * 0.1; // Move 10% towards target each update (100ms)
        if (displayedAngle > 180.0) displayedAngle -= 360.0;
        if (displayedAngle < -180.0) displayedAngle += 360.0;

        // Clear the destination canvas (fill with transparent color)
        lv_canvas_fill_bg(canvas, lv_color_make(0, 0, 0), LV_OPA_TRANSP);

        // Get the source image descriptor
        lv_img_dsc_t *src_img = lv_canvas_get_img(source_canvas);

        // Apply transformation to rotate the arrow
        lv_canvas_transform(
            canvas,                    // Destination canvas
            src_img,                   // Source image descriptor
            (int16_t)(displayedAngle * 10), // Angle in 0.1 degrees (LVGL convention)
            256,                       // Zoom factor (256 = no zoom)
            0,                         // Offset X
            0,                         // Offset Y
            arrow_width / 2,           // Pivot X (center of canvas)
            120,          // Pivot Y (center of canvas)
            true                       // Enable anti-aliasing
        );

        // Apply transformation to rotate the arrow
        lv_canvas_transform(
            source_canvas,                    // Destination canvas
            src_img,                   // Source image descriptor
            (int16_t)0, // Angle in 0.1 degrees (LVGL convention)
            256,                       // Zoom factor (256 = no zoom)
            0,                         // Offset X
            120,                         // Offset Y
            0,           // Pivot X (center of canvas)
            0,          // Pivot Y (center of canvas)
            true                       // Enable anti-aliasing
        );

        // Show the destination canvas
        lv_obj_clear_flag(canvas, LV_OBJ_FLAG_HIDDEN);

        // Update the label with the displayed angle
        char angleStr[16];
        snprintf(angleStr, sizeof(angleStr), "%.1f", displayedAngle);
        lv_label_set_text(directionTxt, angleStr);
    } else {
        // Hide the destination canvas when angle is invalid
        lv_obj_add_flag(canvas, LV_OBJ_FLAG_HIDDEN);
        lv_label_set_text(directionTxt, "No Data");
    }
}

void apply_background_color()
{
  // Set background color to black
  lv_obj_set_style_bg_color(scr, palette_black, LV_PART_MAIN);
  lv_obj_set_style_bg_opa(scr, LV_OPA_COVER, LV_PART_MAIN);
}

void draw_compass_background()
{
  // Create arc
  arc1 = lv_arc_create(scr);
  lv_obj_set_size(arc1, arc1_size, arc1_size); // Set arc size (230x230)
  lv_obj_align(arc1, LV_ALIGN_CENTER, 0, 0);  // Center the arc
  lv_arc_set_bg_angles(arc1, arc_end, arc_start); // Set background angles (0 to 180)
  lv_arc_set_range(arc1, -compass_max_angle, compass_max_angle); // Set range (-90 to 90)
  lv_arc_set_value(arc1, compass_max_angle); // Set value to max (90)

  // Style the arc
  lv_obj_set_style_arc_color(arc1, palette_black, LV_PART_MAIN); // Background arc color
  lv_obj_set_style_arc_opa(arc1, LV_OPA_COVER, LV_PART_MAIN); // Ensure background is opaque
  lv_obj_set_style_arc_color(arc1, palette_dark_green, LV_PART_INDICATOR); // Indicator color
  lv_obj_set_style_arc_opa(arc1, LV_OPA_COVER, LV_PART_INDICATOR); // Ensure indicator is opaque
  lv_obj_set_style_arc_width(arc1, arc1_width, LV_PART_INDICATOR); // Set indicator width to 15
  lv_obj_set_style_arc_rounded(arc1, false, LV_PART_INDICATOR); // Sharp ends for indicator
  lv_obj_remove_style(arc1, NULL, LV_PART_KNOB); // Remove knob

  // Create arc
  arc2 = lv_arc_create(scr);
  lv_obj_set_size(arc2, arc2_size, arc2_size); // Set arc size (230x230)
  lv_obj_align(arc2, LV_ALIGN_CENTER, 0, 0);  // Center the arc
  lv_arc_set_bg_angles(arc2, arc_end, arc_start); // Set background angles (0 to 180)
  lv_arc_set_range(arc2, -compass_max_angle, compass_max_angle); // Set range (-90 to 90)
  lv_arc_set_value(arc2, compass_max_angle); // Set value to max (90)

  // Style the arc
  lv_obj_set_style_arc_color(arc2, palette_black, LV_PART_MAIN); // Background arc color
  lv_obj_set_style_arc_opa(arc2, LV_OPA_COVER, LV_PART_MAIN); // Ensure background is opaque
  lv_obj_set_style_arc_color(arc2, palette_green, LV_PART_INDICATOR); // Indicator color
  lv_obj_set_style_arc_opa(arc2, LV_OPA_COVER, LV_PART_INDICATOR); // Ensure indicator is opaque
  lv_obj_set_style_arc_width(arc2, arc2_width, LV_PART_INDICATOR); // Set indicator width to 15
  lv_obj_set_style_arc_rounded(arc2, false, LV_PART_INDICATOR); // Sharp ends for indicator
  lv_obj_remove_style(arc2, NULL, LV_PART_KNOB); // Remove knob

  // Create arc
  arc3 = lv_arc_create(scr);
  lv_obj_set_size(arc3, arc3_size, arc3_size); // Set arc size (230x230)
  lv_obj_align(arc3, LV_ALIGN_CENTER, 0, 0);  // Center the arc
  lv_arc_set_bg_angles(arc3, arc_end, arc_start); // Set background angles (0 to 180)
  lv_arc_set_range(arc3, -compass_max_angle, compass_max_angle); // Set range (-90 to 90)
  lv_arc_set_value(arc3, compass_max_angle); // Set value to max (90)

  // Style the arc
  lv_obj_set_style_arc_color(arc3, palette_black, LV_PART_MAIN); // Background arc color
  lv_obj_set_style_arc_opa(arc3, LV_OPA_COVER, LV_PART_MAIN); // Ensure background is opaque
  lv_obj_set_style_arc_color(arc3, palette_dark_green, LV_PART_INDICATOR); // Indicator color
  lv_obj_set_style_arc_opa(arc3, LV_OPA_COVER, LV_PART_INDICATOR); // Ensure indicator is opaque
  lv_obj_set_style_arc_width(arc3, arc3_width, LV_PART_INDICATOR); // Set indicator width to 15
  lv_obj_set_style_arc_rounded(arc3, false, LV_PART_INDICATOR); // Sharp ends for indicator
  lv_obj_remove_style(arc3, NULL, LV_PART_KNOB); // Remove knob
}

// Method to set up the arrow on a canvas
// If using dual canvas' does not work, try mathematically changing the arrow_point positions to rotate the arrow.
// https://grok.com/chat/fc26102f-532a-4a35-8cd6-87b2427b83ea
// Use pjthompson as login. This chat includes mathematical rotation matrix logic.
void draw_arrow() {
    // Create source canvas for the arrow
    source_canvas = lv_canvas_create(scr);
    lv_obj_set_size(source_canvas, arrow_width, arrow_height); // Set canvas size to 84x128
    lv_obj_align(source_canvas, LV_ALIGN_CENTER, 0, 0); // Center the source canvas (optional, can be hidden)
    lv_obj_add_flag(source_canvas, LV_OBJ_FLAG_HIDDEN); // Hide source canvas as it's only for rendering

    // Allocate buffer for the source canvas (RGBA format for transparency)
    static lv_color_t source_cbuf[LV_CANVAS_BUF_SIZE_TRUE_COLOR_ALPHA(arrow_width, arrow_height)];
    lv_canvas_set_buffer(source_canvas, source_cbuf, arrow_width, arrow_height, LV_IMG_CF_TRUE_COLOR_ALPHA);

    // Define arrow points
    lv_point_t arrow_points[] = {
        {36, 127}, // Base right
        {47, 127}, // Base left
        {59, 74},  // Inner left
        {83, 74},  // Outer left
        {42, 0},   // Tip (top)
        {0, 74},   // Outer right
        {24, 74},  // Inner right
        {36, 127}  // Back to start
    };

    // Define fill descriptor
    lv_draw_line_dsc_t line_dsc_fill;
    lv_draw_line_dsc_init(&line_dsc_fill);
    line_dsc_fill.color = palette_green; // Green fill color
    line_dsc_fill.width = 1;             // Thinner lines for fill
    line_dsc_fill.opa = LV_OPA_COVER;    // Fully opaque

    // Define outline descriptor
    lv_draw_line_dsc_t line_dsc_outline;
    lv_draw_line_dsc_init(&line_dsc_outline);
    line_dsc_outline.color = palette_black; // Black outline color
    line_dsc_outline.width = 2;             // Slightly thicker outline
    line_dsc_outline.opa = LV_OPA_COVER;    // Fully opaque

    // Draw the fill by approximating with horizontal lines
    for (int y = 0; y < arrow_height; y += 1) {
        int x_left = arrow_width, x_right = 0;
        for (int i = 0; i < arrow_point_count; i++) {
            lv_point_t p1 = arrow_points[i];
            lv_point_t p2 = arrow_points[(i + 1) % arrow_point_count]; // Close the loop
            if ((p1.y <= y && p2.y > y) || (p2.y <= y && p1.y > y)) {
                int x = p1.x + (y - p1.y) * (p2.x - p1.x) / (p2.y - p1.y);
                if (x < x_left) x_left = x;
                if (x > x_right) x_right = x;
            }
        }
        if (x_right > x_left) {
            lv_point_t fill_points[] = {{x_left, y}, {x_right, y}};
            lv_canvas_draw_line(source_canvas, fill_points, 2, &line_dsc_fill);
        }
    }

    // Draw the outline by connecting points with lines
    for (int i = 0; i < arrow_point_count; i++) {
        lv_point_t line_points[] = {arrow_points[i], arrow_points[(i + 1) % arrow_point_count]};
        lv_canvas_draw_line(source_canvas, line_points, 2, &line_dsc_outline);
    }

    // Create destination canvas for the rotated arrow
    canvas = lv_canvas_create(scr);
    lv_obj_set_size(canvas, arrow_width, arrow_height); // Same size as source
    lv_obj_align(canvas, LV_ALIGN_CENTER, 0, 0); // Center the destination canvas

    // Allocate buffer for the destination canvas
    static lv_color_t dest_cbuf[LV_CANVAS_BUF_SIZE_TRUE_COLOR_ALPHA(arrow_width, arrow_height)];
    lv_canvas_set_buffer(canvas, dest_cbuf, arrow_width, arrow_height, LV_IMG_CF_TRUE_COLOR_ALPHA);

    // Initially hide the destination canvas
    lv_obj_add_flag(canvas, LV_OBJ_FLAG_HIDDEN);
}

void draw_angle_label(){
/* Direction text label */
  directionTxt = lv_label_create(scr);
  char angleStr[16]; // Buffer for string conversion
  if (currentAngle >= -180.0 && currentAngle <= 180.0) {
    snprintf(angleStr, sizeof(angleStr), "%.1f", currentAngle); // Convert float to string
    lv_label_set_text(directionTxt, angleStr);
  } else {
    lv_label_set_text(directionTxt, "No Data");
  }
  lv_obj_align(directionTxt, LV_ALIGN_CENTER, 0, -20);
}

/* Display background and meter widget */
void lv_example_page(void) {
  
  scr = lv_scr_act();

  apply_background_color();

  draw_compass_background();

  draw_arrow();

  draw_angle_label();
}

void setup() {
  Serial.begin(115200);
  // Initialize UART1 with default pins (GPIO20 RX, GPIO21 TX) to match LILYGO's 115200 baud, 8N1
  SerialUART.begin(115200, SERIAL_8N1/*, RX_PIN, TX_PIN*/);
  Serial.println("Setup started");

#ifdef GFX_BL
  pinMode(GFX_BL, OUTPUT);
  digitalWrite(GFX_BL, LOW);
#endif
  gfx->begin(80000000);
  Serial.println("GFX initialized");

  lv_init();
  delay(10);
  Serial.println("LVGL initialized");

  /* Initialize button */
  button.attach(ROTARY_ENCODER_BUTTON_PIN, INPUT);
  button.interval(5);
  Serial.println("Button initialized");

  /* Initialize encoder */
  myEnc.write(0);

  /* Allocate display buffers */
  disp_draw_buf1 = (lv_color_t *)heap_caps_malloc(sizeof(lv_color_t) * screenWidth * screenHeight / 8, MALLOC_CAP_INTERNAL | MALLOC_CAP_8BIT);
  disp_draw_buf2 = (lv_color_t *)heap_caps_malloc(sizeof(lv_color_t) * screenWidth * screenHeight / 8, MALLOC_CAP_INTERNAL | MALLOC_CAP_8BIT);

  if (!disp_draw_buf1 && !disp_draw_buf2) {
    Serial.println("LVGL disp_draw_buf allocate failed!");
    return;
  } else {
    lv_disp_draw_buf_init(&draw_buf, disp_draw_buf1, disp_draw_buf2, screenWidth * screenHeight / 8);

    /* Initialize display driver */
    lv_disp_drv_init(&disp_drv);
    disp_drv.hor_res = screenWidth;
    disp_drv.ver_res = screenHeight;
    disp_drv.flush_cb = my_disp_flush;
    disp_drv.draw_buf = &draw_buf;
    lv_disp_t *disp = lv_disp_drv_register(&disp_drv);      // Modified line: capture the display pointer
    lv_disp_set_rotation(disp, LV_DISP_ROT_270);            // Added line: set rotation to 270 degrees
    Serial.println("Display initialized");

    /* Initialize input device (encoder only) */
    group = lv_group_create();
    static lv_indev_drv_t indev_drv;
    lv_indev_drv_init(&indev_drv);
    indev_drv.type = LV_INDEV_TYPE_ENCODER;
    indev_drv.read_cb = my_encoder_read;
    lv_indev_t *indev_encoder = lv_indev_drv_register(&indev_drv);
    lv_indev_set_group(indev_encoder, group);
    Serial.println("Input devices initialized");

    lv_example_page();
    Serial.println("Example page loaded");

    /* Create timer to update arrow */
    lv_timer_create(update_arrow, 100, NULL);
  }

  /* Create UART task */
  xTaskCreatePinnedToCore(uartTask, "uartTask", 4096, NULL, 1, NULL, 0);
  /* Create LVGL task */
  xTaskCreatePinnedToCore(lvglTask, "lvglTask", 8192, NULL, 2, NULL, 1);

  Serial.println("Setup done");
}

void loop() {

}

/* UART task to read angle from LILYGO */
void uartTask(void *pvParameters) {
  while (true) {
    if (SerialUART.available() >= sizeof(float)) { // Check if at least 4 bytes are available
      float relativeAngle;
      SerialUART.readBytes((uint8_t*)&relativeAngle, sizeof(float)); // Read 4 bytes into float
      Serial.print("Received Relative Angle: ");
      Serial.print(relativeAngle, 1); // Print angle with 1 decimal place for debugging
      Serial.println("° (0° is ahead)");
      
      // Validate angle (LILYGO sends 999.0 for no alert)
      if (relativeAngle >= -180.0 && relativeAngle <= 180.0) {
        currentAngle = relativeAngle; // Update global angle for valid values
      } else {
        currentAngle = 999.0; // Set to sentinel value for invalid/no alert
        Serial.println("No valid police alert received (sentinel value).");
      }
    }
    vTaskDelay(pdMS_TO_TICKS(100)); // Delay 100ms between checks
  }
}

/* LVGL task */
void lvglTask(void *pvParameters) {
  Serial.println("lvglTask started");
  while (true) {
    lv_timer_handler();
    vTaskDelay(pdMS_TO_TICKS(5));
  }
}

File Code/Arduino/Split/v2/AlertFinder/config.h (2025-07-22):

// config.h (Modified)
#ifndef CONFIG_H
#define CONFIG_H

// =========================================================================
// SIM7000G MODEM CONFIGURATION
// =========================================================================
#define TINY_GSM_MODEM_SIM7000
#define TINY_GSM_RX_BUFFER 1024
#define SerialAT Serial1
#define UART_BAUD          115200
#define PIN_TX             27
#define PIN_RX             26
#define PWR_PIN            4

// =========================================================================
// OTHER HARDWARE & PERIPHERALS
// =========================================================================
#define IMU_SDA            21
#define IMU_SCL            22
#define LED_PIN            14
#define NUM_LEDS           46
#define SPEAKER_PIN        25

// =========================================================================
// NETWORKING & API CONFIGURATION
// =========================================================================
extern const char* WIFI_SSID;
extern const char* WIFI_PASSWORD;
extern const char* APN;
extern const char* GPRS_USER;
extern const char* GPRS_PASS;
extern const char* WAZE_HOST;
extern const char* WAZE_PATH;
extern const char* WMM_HOST;
extern const char* WMM_PATH;
extern const char* WMM_API_KEY;

// =========================================================================
// APPLICATION & LOGIC CONSTANTS
// =========================================================================
const float MAX_ALERT_DISTANCE_KM = 50.0f;
const float ALERT_CHECK_INTERVAL_S = 15.0f;
const float MOVEMENT_THRESHOLD_KM = 0.2f;
const float WMM_UPDATE_DISTANCE_KM = 100.0f;
const unsigned long WMM_UPDATE_INTERVAL_MS = 24 * 60 * 60 * 1000UL;
const unsigned long WMM_RETRY_DELAY_MS = 5 * 60 * 1000UL;
const unsigned long GPS_IMU_PRINT_INTERVAL_MS = 500;
const unsigned long IMU_RETRY_INTERVAL_MS = 5000;
const unsigned long LED_UPDATE_INTERVAL_MS = 50;

// =========================================================================
// FAULT TOLERANCE & DEFAULT VALUES
// =========================================================================
const unsigned long GPS_FIX_TIMEOUT_MS = 300UL;//300000UL; // 5 minutes to get a GPS fix before using defaults
const float DEFAULT_LATITUDE = -33.441344;           // Default location
const float DEFAULT_LONGITUDE = 151.395222;          // Default location

#include <FastLED.h>
const CRGB LED_COLOR = CRGB(128, 255, 0);

#endif // CONFIG_H

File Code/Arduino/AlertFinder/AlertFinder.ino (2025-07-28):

// PARTS (V1.0):
// - LILYGO T-SIM7000G V1.1 ESP32 (this script runs on this device)
// - Viewe ESP32 1.28 Inch 240×240 IOT Smart Display Screen Rotate and Press Circular Knob Screen with WiFi BLE
// - Adafruit Stemma Speaker
// - WS2812B LED strip (46 in total)
// - BNO086 IMU (replacing HMC5883L)

// SIM7000G Configuration
#define TINY_GSM_MODEM_SIM7000
#define TINY_GSM_RX_BUFFER 1024 // Set RX buffer to 1Kb
#define SerialAT Serial1
#define UART_BAUD 115200
#define PIN_TX 27
#define PIN_RX 26
#define PWR_PIN 4

// ESP32 Communication
#define COMM_TX 32
#define COMM_RX 33

// LED Strip Configuration
#define LED_PIN 14    // GPIO14 on LILYGO ESP32
#define NUM_LEDS 46   // Total number of LEDs

// Speaker Configuration
#define SPEAKER_PIN 25 // GPIO25 for Adafruit STEMMA Speaker signal (DAC1)

// BNO086 Configuration
#define BNO08X_INT  19  // GPIO19 for interrupt
#define BNO08X_RST  23  // GPIO23 for reset
#define BNO08X_ADDR 0x4B  // Default I2C address (0x4A if ADR jumper closed)

// Libraries
#include <HardwareSerial.h>     // For UART communication
#include <TinyGsmClient.h>      // For SIM7000G modem
#include <TinyGPS++.h>          // For parsing GPS data
#include <Wire.h>               // For I2C with BNO086
#include "SparkFun_BNO08x_Arduino_Library.h"  // For BNO086 IMU
#include <WiFi.h>               // For Wi-Fi connectivity
#include <WiFiClientSecure.h>   // For secure HTTPS requests
#include <HTTPClient.h>         // For HTTP requests to Waze API and NOAA WMM
#include <ArduinoJson.h>        // For parsing JSON responses
#include <FastLED.h>            // For WS2812B LED strip control
#include <freertos/FreeRTOS.h>  // For FreeRTOS tasks
#include <freertos/task.h>      // For task management
#include <AudioFileSourcePROGMEM.h> // For playing audio from PROGMEM
#include <AudioGeneratorWAV.h>      // For WAV file playback
#include <AudioOutputI2S.h>         // For audio output to DAC
#include "alert_wav.h"              // Include the custom sound file byte array

// Configuration Constants
const char* ssid = "BigCock69";     // Replace with your Wi-Fi SSID
const char* password = "GymBro69";  // Replace with your Wi-Fi password
const char apn[] = "";              // SET TO YOUR APN
const char gprsUser[] = "";
const char gprsPass[] = "";
const float maxDistanceKm = 5.0f;      // Max distance for alerts (kilometers)
const float checkInterval = 45.0f;      // Interval to check for new alerts (seconds)
const float movementThreshold = 0.2f;   // Distance to trigger alert check (kilometers)
const float wmmUpdateDistance = 100.0f; // Distance to trigger WMM update (kilometers)
const unsigned long wmmUpdateInterval = 24 * 60 * 60 * 1000UL; // Check WMM daily (ms)
const unsigned long wmmRetryDelay = 5 * 60 * 1000UL; // Retry after 5 minutes on API error
const char* baseHost = "www.waze.com";  // Waze API host
const char* basePath = "/live-map/api/georss"; // Waze API path
const char* wmmHost = "www.ngdc.noaa.gov"; // NOAA WMM API host
const char* wmmPath = "/geomag-web/calculators/calculateDeclination"; // NOAA WMM API path
const unsigned long printInterval = 500;         // Print GPS/IMU data every 500ms
const unsigned long retryInterval = 5000;        // Retry BNO086 initialization every 5s
const unsigned long receivePrintInterval = 1000; // Print received UART data every 1000ms
const unsigned long ledUpdateInterval = 50;      // Update LEDs every 50ms
const int maxImuFailures = 5;                    // Max consecutive IMU failures

// Hardware Objects
HardwareSerial commSerial(2);  // UART2 for communication
TinyGsm modem(SerialAT);       // TinyGSM modem object
TinyGsmClient gsmClient(modem); // TinyGSM client
TinyGPSPlus gps;               // TinyGPS++ object
BNO08x myIMU;                  // BNO086 IMU
CRGB leds[NUM_LEDS];           // LED strip array

// Audio Objects
AudioGeneratorWAV *wav = nullptr;
AudioFileSourcePROGMEM *file = nullptr;
AudioOutputI2S *out = nullptr;

// LED Row Definitions
int row1[] = {0, 1, 2, 3, 4, 5, 6, 7, 8, 9, 10, 11};              // Row 1: LEDs 0 to 11
int row2[] = {22, 21, 20, 19, 18, 17, 16, 15, 14, 13, 12};        // Row 2: LEDs 12 to 22
int row3[] = {23, 24, 25, 26, 27, 28, 29, 30, 31, 32, 33};        // Row 3: LEDs 23 to 33
int row4[] = {45, 44, 43, 42, 41, 40, 39, 38, 37, 36, 35, 34};    // Row 4: LEDs 34 to 45

// Number of LEDs in Each Row
const int num_leds_row1 = 12;
const int num_leds_row2 = 11;
const int num_leds_row3 = 11;
const int num_leds_row4 = 12;

// LED Color and Multiplier
CRGB color = CRGB(128, 255, 0); // R:128, G:255, B:0 (lime green)
volatile float multiplier = 1.0f; // Animation speed multiplier (1.0 to 2.0), volatile for task safety

// State Variables
bool bnoInitialized = false;
int imuFailureCount = 0;
unsigned long lastGpsPrint = 0;
unsigned long lastImuPrint = 0;
unsigned long lastBnoRetry = 0;
unsigned long lastApiCall = 0;
unsigned long lastReceivePrint = 0;
unsigned long lastWmmUpdate = 0; // Timestamp of last WMM update
unsigned long lastWmmAttempt = 0; // Timestamp of last WMM API attempt
float timeSinceLastCheck = 0;
bool isLocationInitialized = false;
float currentDirection = 0;
bool isGprsConnected = false;
volatile int alertCount = 0; // Volatile for task safety
volatile int closestIndex = -1; // Volatile for task safety
volatile bool playSound = false; // Flag to trigger sound in audio task

// Data Structures
struct Location {
  float latitude;
  float longitude;
};
Location currentLocation = {0, 0};
Location lastCheckedLocation = {0, 0};
Location lastWmmLocation = {0, 0}; // Location of last WMM update

// Declination Data Structure
struct DeclinationData {
  float latitude;
  float longitude;
  float declination;
  String modelVersion; // e.g., "WMM2025"
  bool isValid;
};
DeclinationData currentDeclination = {0, 0, 0, "WMM2025", false};

// Data Structures for Alerts
struct Alert {
  String type;
  String subtype;
  Location location;
  String street;
};
Alert* currentAlerts = nullptr;

struct BoundingArea {
  float left;
  float bottom;
  float right;
  float top;
};

// Utility Functions
BoundingArea boundingBox(Location location, float distanceInKm) {
  float latInRadians = location.latitude * PI / 180.0;
  float deltaLatitude = distanceInKm / 111.0;
  float deltaLongitude = distanceInKm / (111.0 * cos(latInRadians));
  BoundingArea area;
  area.left = location.longitude - deltaLongitude;
  area.bottom = location.latitude - deltaLatitude;
  area.right = location.longitude + deltaLongitude;
  area.top = location.latitude + deltaLatitude;
  return area;
}
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

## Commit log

2025-04-29 Alert Detector Start
    [PoliceRadarPrototype_01.skp, PoliceRadarPrototype_02.skp, PoliceRadarPrototype_03.skp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]
2025-05-02 Model V1 Finished (PRP_07)
    [PoliceRadarPrototype_06.skp, PoliceRadarPrototype_07.skp]
2025-05-03 Finished 3D Model
    Printable 3D model
    [PoliceRadarPrototype_07.skp, PoliceRadarPrototype_07.stl, PoliceRadarPrototype_07_Lid.skp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]
2025-05-10 alert receiver GPS start
    [BillOfMaterials.xlsx]
2025-05-18 More Work
    [BillOfMaterials.xlsx]
2025-05-18 GPS Script: FUNCTIONALITY WORKING
    No LTE or data output, however the code outputs the closest police alert found and prints out its relative angle from us.
2025-05-18 Relative angle data is being sent
    Plug in GPIO18 (TX) to GPIO19 (RX) to debug the data being sent to other ESP device
2025-05-19 V1 Wiring Diagram
2025-05-21 3D Model Work
    [PoliceRadarPrototype_07.skp, PoliceRadarPrototype_08.skp]
2025-05-24 GPS testing
    [PoliceRadarPrototype_08.skp]
2025-05-26 Successful loopback test for ESP32 communication
2025-05-27 Success with 10 pin FPC Extender
    Issue was with extension board hardware which came with the Viewe 1.28 inch display. We can order a 10pin FPC 0.5mm extension board to replace it at: https://vi.aliexpress.com/item/1005007145462021.html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
    [AlertRenderer.ino, Test.ino]
2025-05-27 3D print fixed
    [PoliceRadarPrototype_08.skp, PoliceRadarPrototype_08.stl, PoliceRadarPrototype_LED_Rack.skp]
2025-05-27 Successful LED Test
2025-05-27 LED Success
    [PoliceRadarPrototype_08.skp]
2025-05-28 3D touchups and included lv_conf
    [PoliceRadarPrototype_08.skp]
2025-05-28 3D Model Functional
    Closer to end design. This design will likely be used for all of development if all dimensions are correct.
    [PoliceRadarPrototype_09.skp, PoliceRadarPrototype_09.stl]
2025-05-29 Colours are showing correctly
    [AlertRenderer.ino]
2025-05-30 Arrow rotates nicely (WITH ISSUES)
    Has clipping. This is because there is not enough DRAM to display the canvas buffers at 154x154. 154x154 is required to keep arrow from clipping.
    [AlertRenderer.ino, Test.ino]
2025-05-31 Accidental pin change reversed
    [AlertFinder.ino]
2025-06-01 LED Fix + Planning
    [AlertFinder.ino]
2025-06-02 Modelling work
    [PoliceRadarPrototype_10.skp]
2025-06-28 Code reorganisation
    Code has been split up into modules, so each physical module can have its own script.
    BNO086 came out to be a dead end. Whilst it seemed to work, after more research it seems it is too unreliable.
    Adafruit LSM6DSOX + LIS3MDL seems like the way to go, as it's newer and has been tested with aviation purposes with positive reviews.
    This code includes the last BNO086 implementation.
    [BillOfMaterials.xlsx, PoliceRadarPrototypeMini_1.skp]
2025-07-23 Compass GUI for 1.75i + model
    [PoliceRadar01_Flat.3mf, PoliceRadar06_Enclosure.3mf, PoliceRadar07.skp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]
2025-07-25 Heatbar animations
2025-07-25 Heatbar animations perfected
2025-07-26 knob model
    needs adjusting but is a good start
    [Knobs.skp, Knobs.stl, PoliceRadar09.skp]
2025-07-28 Adapter
    Adapter is still kinda weak, but will do for now. Still haven't tested with anything but PLA, that could be the issue but we'll see
    [Adapter.stl, Adapter01.stl, Adapter02Holder.stl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]
2025-07-29 modeling + split scripts
    [Adapter.stl, Adapter01.stl, Adapter02Holder.stl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]
2025-07-30 Printer settings
    [PoliceRadar01_Flat.3mf]
2025-07-30 messing around with compass
    compass not working yet
    [AlertFinder.ino, AlertRenderer.cpp, Compass.cpp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]
2025-08-01 Modeling + wiring diagram
    [Adapter.stl, Enclosure.stl, Holder.stl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]
2025-08-02 Adapter work
    trying to perfect. This might actually work with the stronger filament PETG, but is making PLA snap. Is a very good and tight fitment however
    [Adapter.stl, Enclosure.stl, Holder.stl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]
2025-08-06 More modelling
    [Lid.stl, PoliceRadar01_Flat.3mf, PoliceRadar13.skp]
2025-08-09 Work on makeshift PCB
    3D modeling a PCB-like wiring harness and making a wiring diagram directly for it. Both have been started but still needs finishing.
    Change to using a 12v input with a 2.1mm barrel jack connector as power may exceed USB 2 speeds which we don't want. Also a direct connect for connecting directly to battery.
    [PoliceRadar14.skp]
2025-08-12 Wiring work
    [PoliceRadar01_Flat.3mf, PoliceRadar14.skp, WiringHarness.stl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]
2025-08-12 module holder/wiring harness work
    [Adapter.stl, Enclosure.stl, Holder.stl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]
2025-08-13 new part - gps holder
    Still needs work - need screw holes for gps holder to screw in to enclosure
    [PoliceRadar14.skp]
2025-08-13 Screw holes for gps holder
    [PoliceRadar14.skp]
2025-08-13 update
    Need to shorten enclosure and fix board shape
    [PoliceRadar14.skp]
2025-08-14 Model GPS size fix
    [PoliceRadar14.skp]
2025-08-17 Added wire trays
    [PoliceRadar01_Flat.3mf, PoliceRadar14.skp]
2025-08-21 Designing schematic
    Completed dual 12V inputs and converting them to 5V.
    The rest of the circuit still remains.
    [PoliceRadar15.skp, kiCadWiringDiagram.kicad_sch]
2025-08-21 5v to 10v conversion looks complete
    fixed polarized capacitors
    [kiCadWiringDiagram.kicad_sch]
2025-08-21 Schematic done I think
    [kiCadWiringDiagram.kicad_sch]
2025-08-21 need to add motor driver ic
    [kiCadWiringDiagram.kicad_sch]
2025-08-21 Needs IO expander as motor driver takes 6 GPIO pins
    [kiCadWiringDiagram.kicad_sch]
2025-08-21 Schematic now done I think
    [kiCadWiringDiagram.kicad_sch]
2025-08-21 pull up resisters added to i2c bus
    now finished schematic I think
    [kiCadWiringDiagram.kicad_sch]
2025-08-22 Started Footprint assignments
    [PoliceRadar01_Flat.3mf, PoliceRadar15.skp, kiCadWiringDiagram.kicad_sch]
2025-08-22 Completed footprints
    [kiCadWiringDiagram.kicad_sch]
2025-08-22 started work on PCB
    [kiCadWiringDiagram.kicad_pcb]
2025-10-22 Update README with project pictures
    Expanded on project details, including parts sourcing and pictures of the device
2025-10-22 Include pictures of the device in README
    Added a section for device pictures in the README.
2025-10-22 Update README with additional details
    Added random details about screws and versions.
2025-10-24 File cleanup
    [Adapter.stl, Adapter01.stl, Adapter02Holder.stl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]
2025-10-24 Enhance README with PCB usage and component details
    Updated README with additional warnings and notes on PCB and components.
2025-10-24 Revise README with project details and future plans
    Updated project description and added details about future functionalities and current limitations. Removed some redundant information and clarified the use of the device.
2025-10-24 Update header description in README
    Clarified the description of the 8 pin male header in the README.
2025-10-25 Add task for modeling universal mirror mounts
    Added a task to model universal mirror mounts for device stability.
